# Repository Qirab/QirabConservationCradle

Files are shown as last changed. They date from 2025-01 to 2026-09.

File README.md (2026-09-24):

# Qirab™ Conservation Cradle - QCC50 & QCC70

حامل قِراب لترميم المخطوطات هو تصميم مفتوح المصدر لدعم وتثبيت المخطوطات اثناء عمليات الترميم والصيانة

An open-source manuscript repair support hardware design

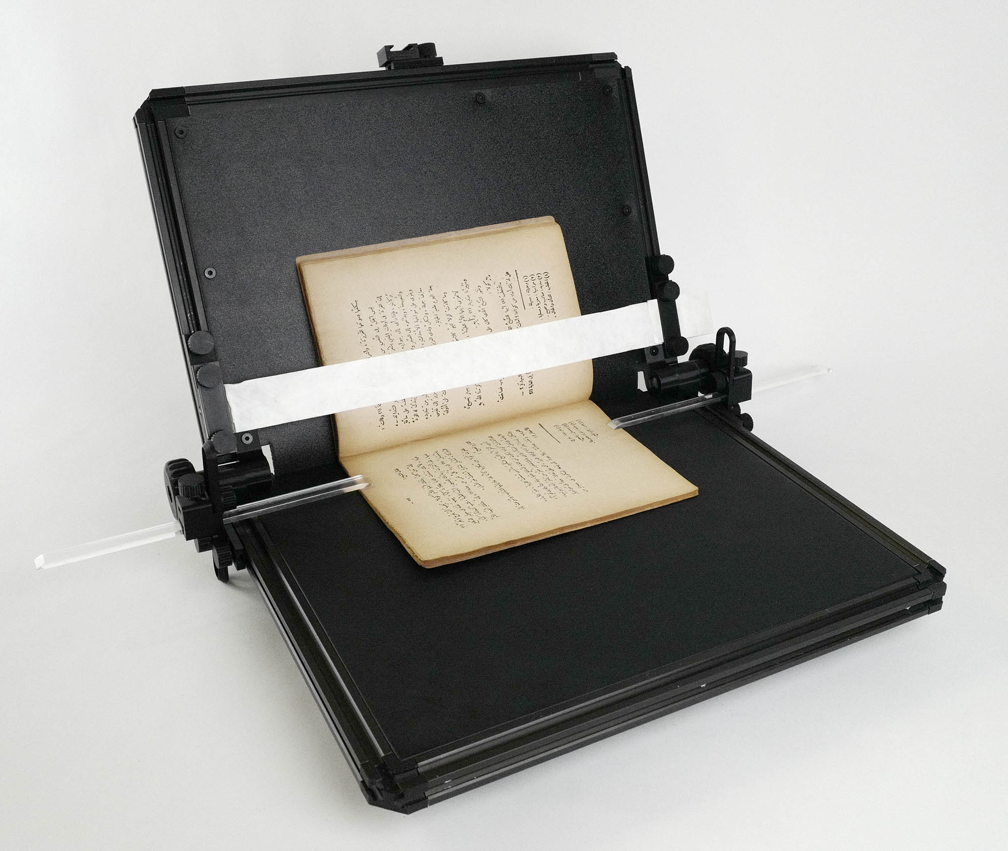
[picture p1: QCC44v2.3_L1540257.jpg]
QCC44v2.3

QC44 v2.3

تم تصميم حامل قِراب لترميم المخطوطات بهدف الحفاظ على المجلدات مفتوحة بشكل آمن أثناء عمليات الترميم والصيانة، والتحليل العلمي، والتوثيق، وأعمال الحفظ. يُسهل هذا الحامل تثبيت المجلدات دون الحاجة لاستخدام اليدين في وضعية ثابتة وقابلة للتعديل وبدون الحاجة للضغط الشديد.

إقرأ المزيد [حامل قِرَاب لترميم المخطوطات - QCC50](https://qirab.org/docs/hardware/conservationcradle/).

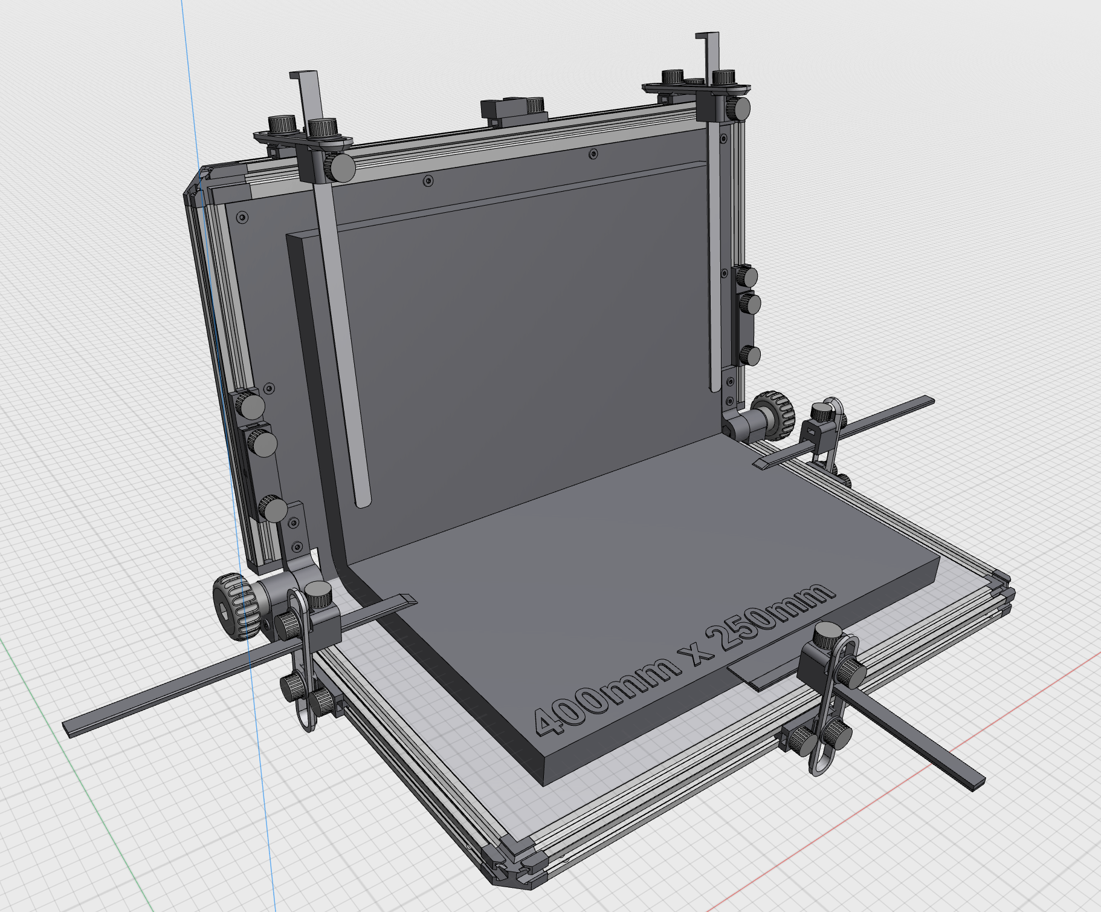
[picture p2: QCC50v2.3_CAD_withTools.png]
QCC55v2.3 CAD rendering with Tools

QCC50 v2.3 CAD rendering with Tools

The Qirab™ Conservation Cradle is an open-source book support design intended to securely hold books open during conservation treatment, scientific analysis, documentation, and preservation works. It facilitates a hands-free holding of the book in a stable and adjustable position without extreme pressure.

Read more on the [Qirab™ project page](https://qirab.org/en/docs/hardware/conservationcradle/).

<br />This work is licensed under a <a rel="license" href="http://creativecommons.org/licenses/by-sa/4.0/">Creative Commons Attribution-ShareAlike 4.0 International License</a>.

<br />هذا المُصنَّف مرخص بموجب <a rel="license" href="http://creativecommons.org/licenses/by-sa/4.0/">رخصة المشاع الإبداعي نَسب المُصنَّف - الترخيص بالمثل 4.0 دولي</a>.

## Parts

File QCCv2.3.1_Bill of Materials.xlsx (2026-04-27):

QCC Bill of Materials
Common Items for QCC50 and QCC75
Item Name | Item Count | Item Type | Item QID | Comment
Hinge Knob | 2 | 3D Print
Hinge Upper Right | 1 | 3D Print
Hinge Upper Left | 1 | 3D Print
Corner 40x20 Right | 1 | 3D Print
Corner 40x20 Left | 1 | 3D Print
~~Rubber Channel Guide~~ | DEPRECATED | 3D Print |  | Removed in v2.3.1
Hinge Left Bottom | 1 | 3D Print
Hinge Right Bottom | 1 | 3D Print
Corner 20x20 | 2 | 3D Print
Foot Lower | 4 | 3D Print
Foot Upper | 4 | 3D Print
Foot Drill Guide | 1 | 3D Print |  | For Assembly Only
OpenBuilds T-Nut | 14 | Hardware
6mm OpenBuilds M5 Low Profile | 6 | Hardware
10mm OpenBuilds M5 Low Profile | 4 | Hardware
15mm OpenBuilds M5 Low Profile | 12 | Hardware
20mm OpenBuilds M5 Low Profile | 0 | Hardware
25mm OpenBuilds M5 Low Profile | 4 | Hardware
M8 Zinc-Plated Steel Hex Nut 90591A161 | 2 | Hardware
M8 Medium-Strength Class 8.8 Steel Hex Head Screw 91280A548 | 2 | Hardware
Stainless Steel Oversized Washer 91116A330 | 6 | Hardware
Flat Head Screws for Particleboard and Fiberboard 90252A247 | 18 | Hardware
M6 Medium-Strength Class 8.8 Steel Hex Head Screw 91280A322 | 4 | Hardware
M6 Zinc-Plated Steel Hex Nut 90591A151 | 4 | Hardware
QCC50 Only Items
Item Name | Item Count | Item Type | Item QID | Comment
20x20x440 mm Frame Bar - OpenBuilds V-Slot Aluminum Profile | 2 | Aluminum
20x40x440 mm Frame Top - OpenBuilds V-Slot Aluminum Profile | 1 | Aluminum
20x40x267 Frame Side - OpenBuilds V-Slot Aluminum Profile | 2 | Aluminum
20x20x286 Base Side - OpenBuilds V-Slot Aluminum Profile | 2 | Aluminum
20x20x463 Front Base Bar - OpenBuilds V-Slot Aluminum Profile | 1 | Aluminum
IKEA Skrutt Desk Mat | 1 | Rubber |  | Cut to pattern; Clear or Black
Wood Counter Top 480x302x28mm IKEA | 1 | Wood |  | Cut from larger worktop
Box QCC50 | 4 | 3D Print
Box Lid QCC50 | 4 | 3D Print
QCC70 Only Items
Item Name | Item Count | Item Type | Item QID | Comment
20x20x610 mm Frame Bar - OpenBuilds V-Slot Aluminum Profile | 2 | Aluminum
20x40x610 mm Frame Top - OpenBuilds V-Slot Aluminum Profile | 1 | Aluminum
20x40x392 Frame Side - OpenBuilds V-Slot Aluminum Profile | 2 | Aluminum
20x20x411 Base Side - OpenBuilds V-Slot Aluminum Profile | 2 | Aluminum
20x20x633 Front Base Bar - OpenBuilds V-Slot Aluminum Profile | 1 | Aluminum
IKEA Skrutt Desk Mat | 1 | Rubber |  | Mostly uncut; Clear or Black
Wood Counter Top 640x427x28mm IKEA | 1 | Wood |  | Cut from larger worktop
Box QCC70 | 4 | 3D Print
Box Lid QCC70 | 4 | 3D Print
QCC44 Only Items - Development Cradle
Item Name | Item Count | Item Type | Item QID | Comment
20x20x362mm Frame Bar - OpenBuilds V-Slot Aluminum Profile | 2 | Aluminum
20x40x362 Frame Top - OpenBuilds V-Slot Aluminum Profile | 1 | Aluminum
20x40x257 Frame Side - OpenBuilds V-Slot Aluminum Profile | 2 | Aluminum
20x20x303 Base Side - OpenBuilds V-Slot Aluminum Profile | 2 | Aluminum
20x20x385 Front Base Bar - OpenBuilds V-Slot Aluminum Profile | 1 | Aluminum
IKEA Skrutt Desk Mat | 1 | Rubber |  | Cut to pattern; Clear or Black
Wood Counter Top 402x312x28mm IKEA | 1 | Wood |  | Cut from larger worktop
Box QCC44 | 4 | 3D Print
Box Lid QCC44 | 4 | 3D Print

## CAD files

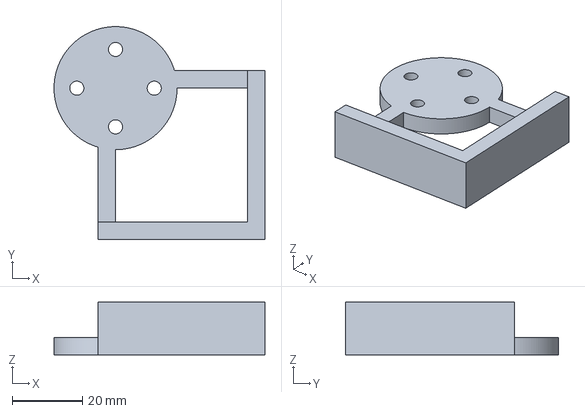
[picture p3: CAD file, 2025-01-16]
3DPRINT/3MF/QCC Foot Drill Guide (for assembly only).3mf
60.0 x 60.5 x 15.0 mm

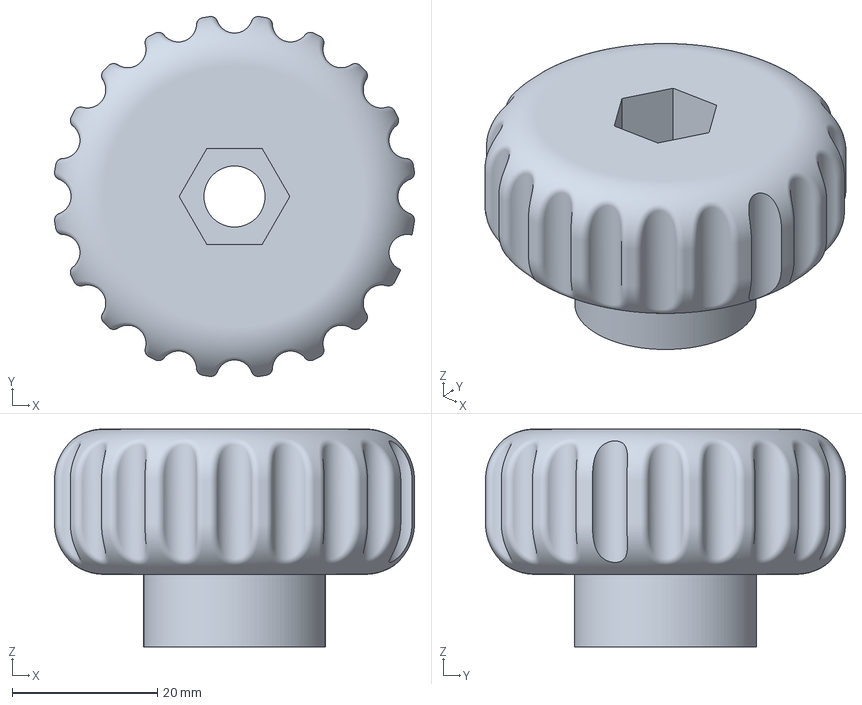
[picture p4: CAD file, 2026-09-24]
3DPRINT/3MF/QCC Hinge Knob.3mf
49.6 x 49.6 x 30.0 mm

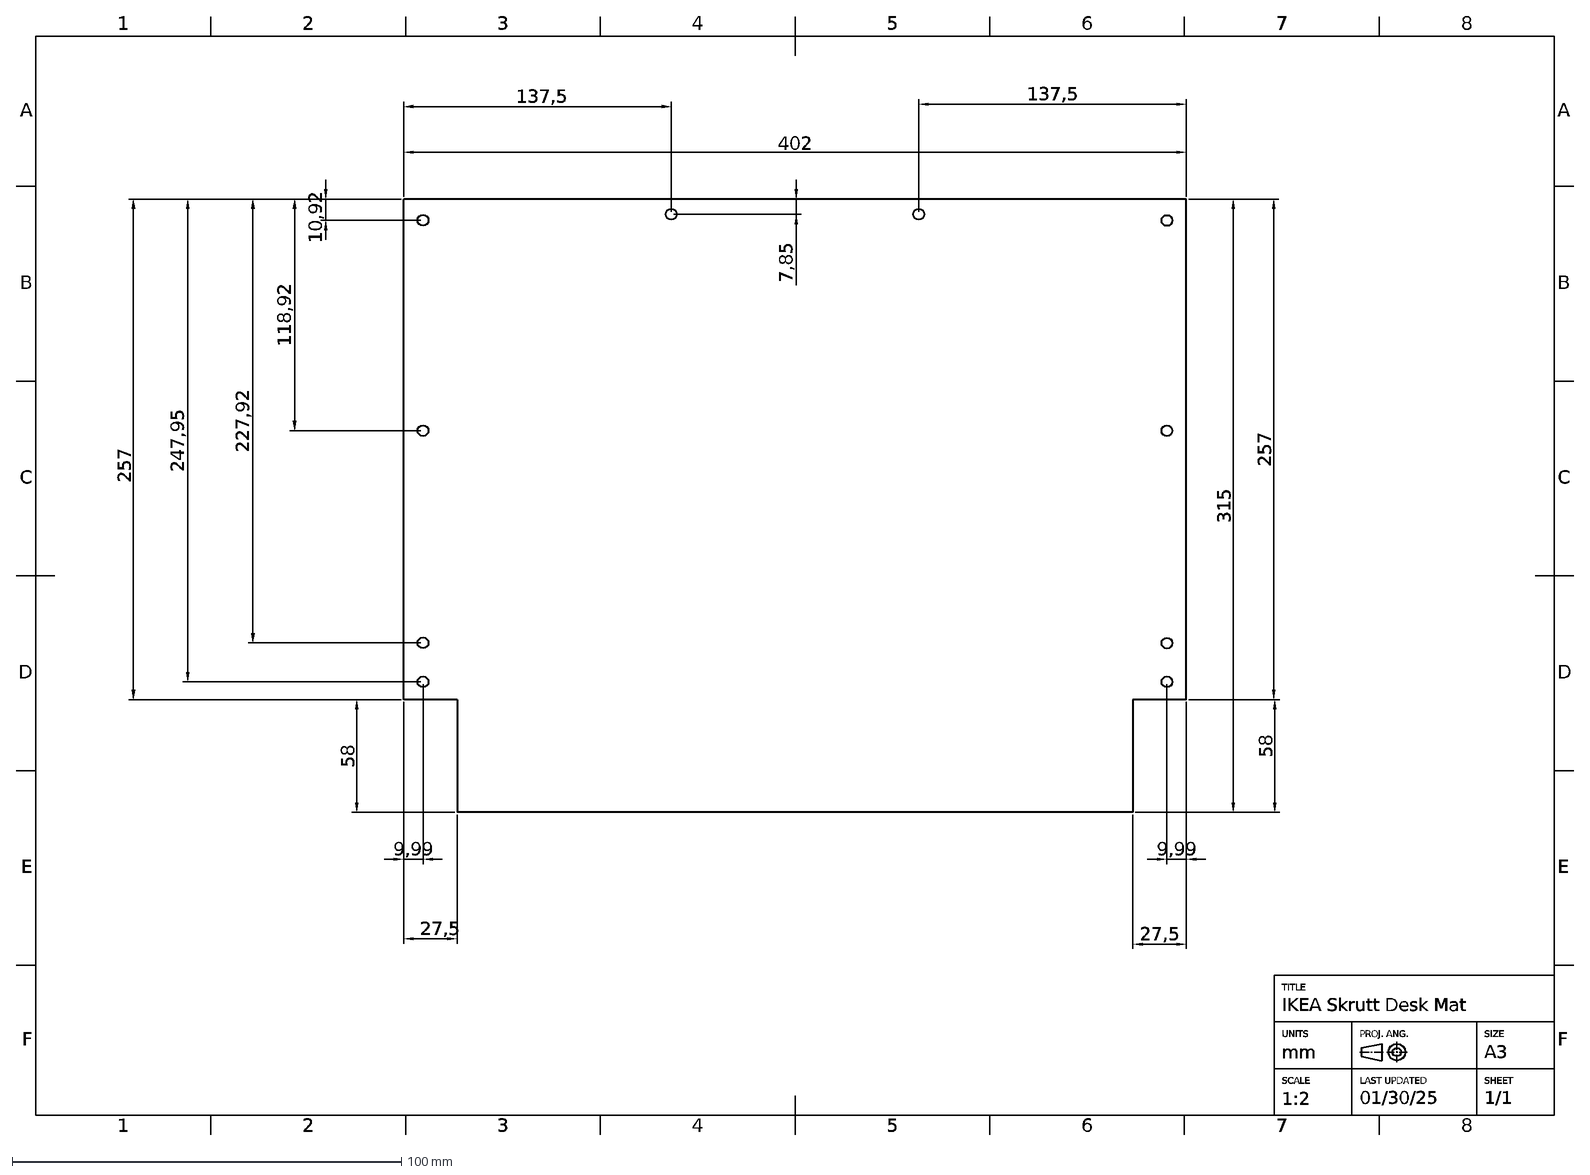
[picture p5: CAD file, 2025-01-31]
PDF/QCC44/QCC44 V2.3 IKEA SKRUT MAT.dxf
7,85
257
58
27,5
137,5
247,95
227,92
118,92
10,92
9,99
315
402
1
2
3
4
5
6
7
8
F
E
D
C
B
A
TITLE
IKEA Skrutt Desk Mat
UNITS
mm
PROJ. ANG.
SIZE
A3
SCALE
1:2
LAST UPDATED
01/30/25
SHEET
1/1

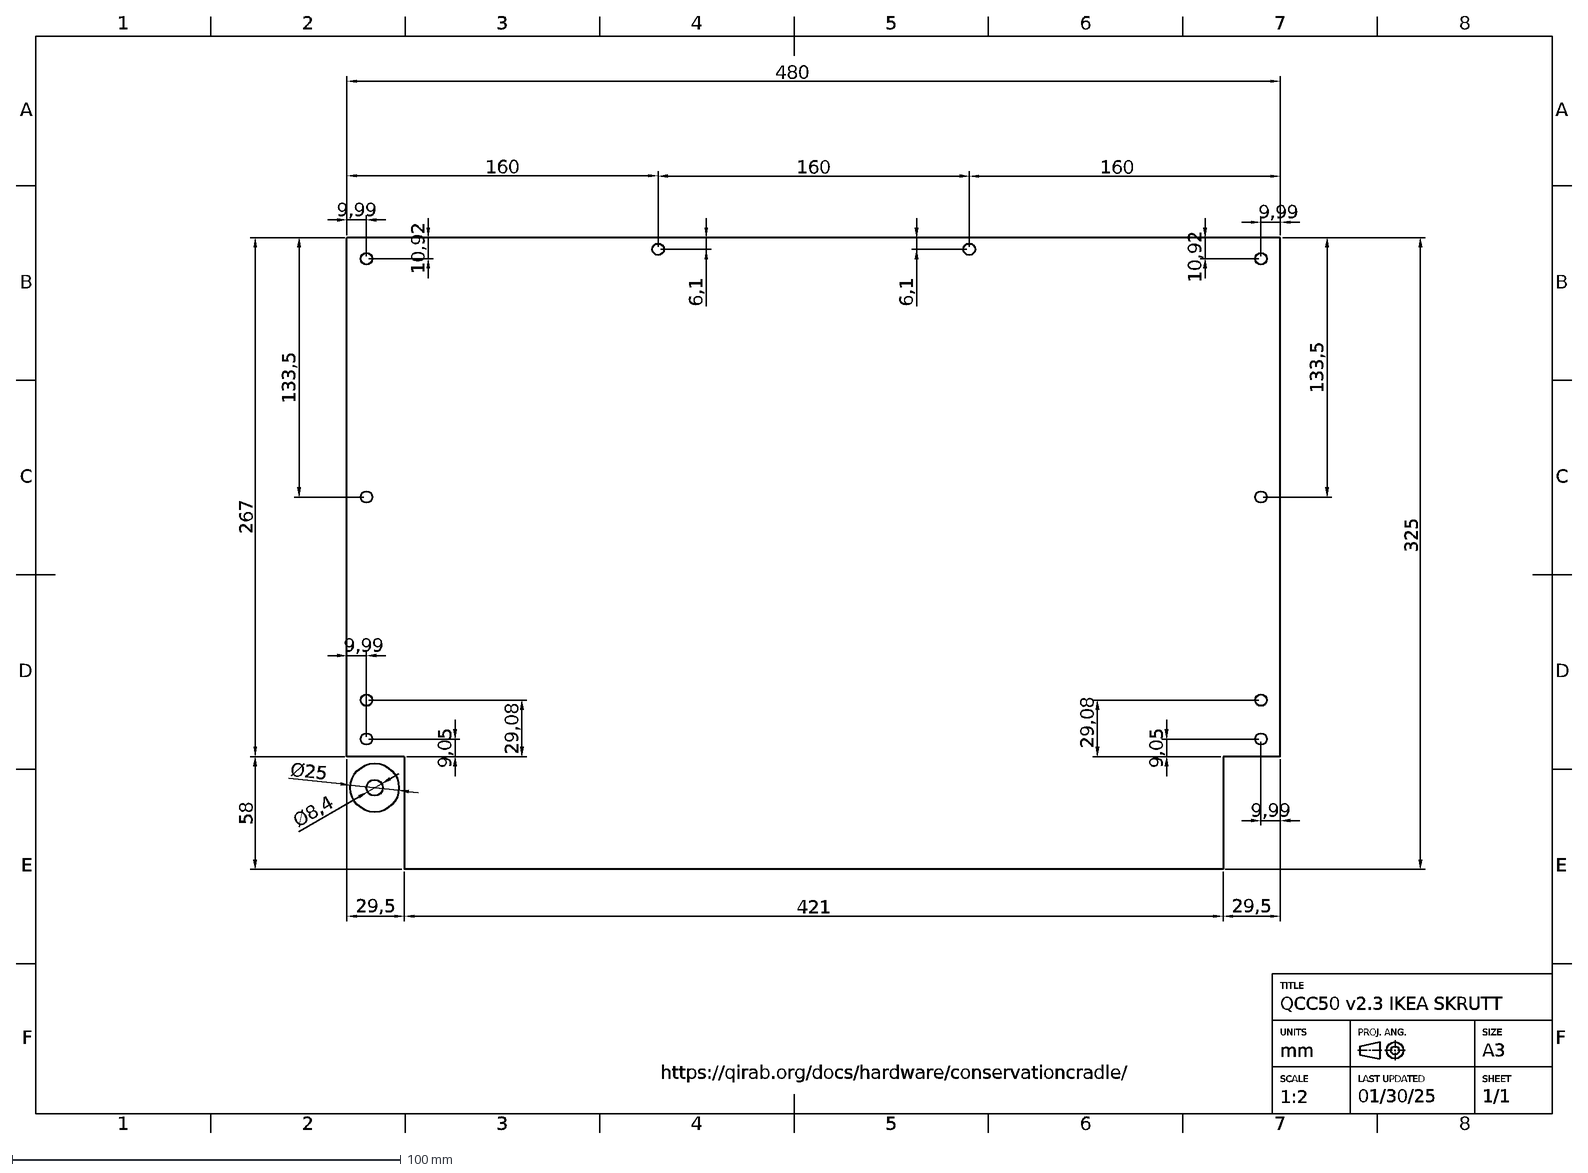
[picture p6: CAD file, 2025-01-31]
PDF/QCC50 v2.3 IKEA SKRUTT.dxf
58
133,5
160
Ø25
10,92
29,08
Ø8,4
9,99
421
29,5
325
6,1
480
9,05
267
1
2
3
4
5
6
7
8
F
E
D
C
B
A
TITLE
QCC50 v2.3 IKEA SKRUTT
UNITS
mm
PROJ. ANG.
SIZE
A3
https://qirab.org/docs/hardware/conservationcradle/
01/30/25
1:2
LAST UPDATED
SHEET
SCALE
1/1

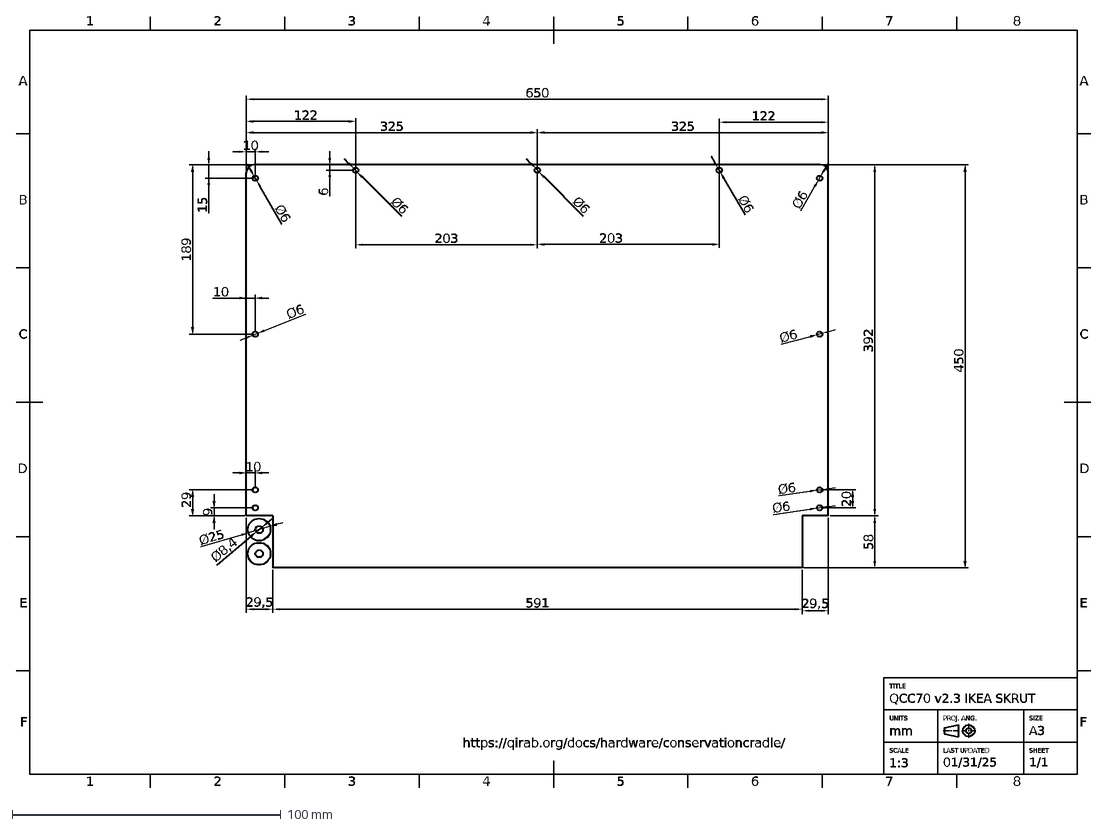
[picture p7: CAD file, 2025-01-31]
PDF/QCC70/QCC70 v2.3 IKEA SKRUT.dxf
650
450
58
392
29,5
591
10
9
29
189
15
6
122
325
Ø6
20
203
Ø25
Ø8,4
1
2
3
4
5
7
8
F
E
D
C
B
A
https://qirab.org/docs/hardware/conservationcradle/
SIZE
QCC70 v2.3 IKEA SKRUT
UNITS
mm
PROJ. ANG.
A3
SCALE
1:3
LAST UPDATED
01/31/25
TITLE
SHEET
1/1

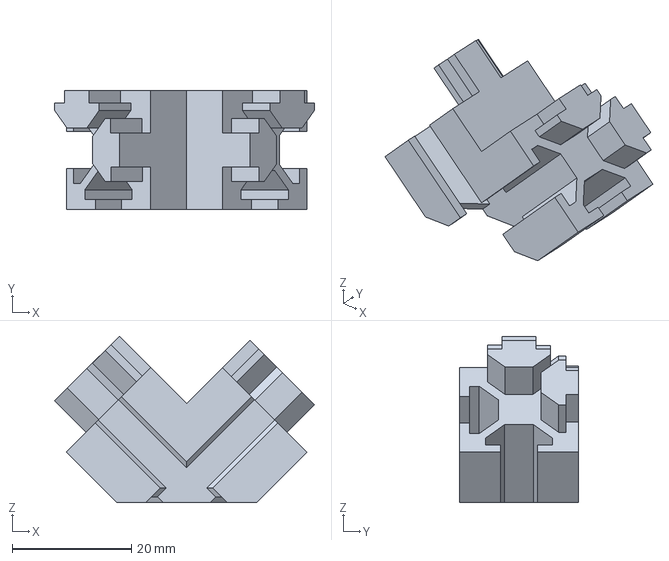
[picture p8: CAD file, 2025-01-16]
3DPRINT/3MF/QCC Corner 20.3mf
43.6 x 20.0 x 27.8 mm

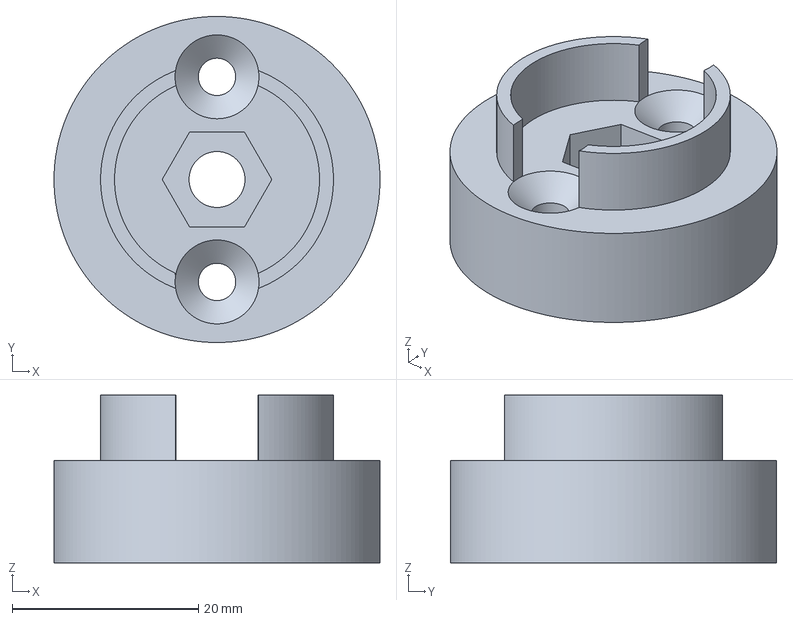
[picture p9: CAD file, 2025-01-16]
3DPRINT/3MF/QCC Foot Upper.3mf
35.0 x 35.0 x 18.0 mm

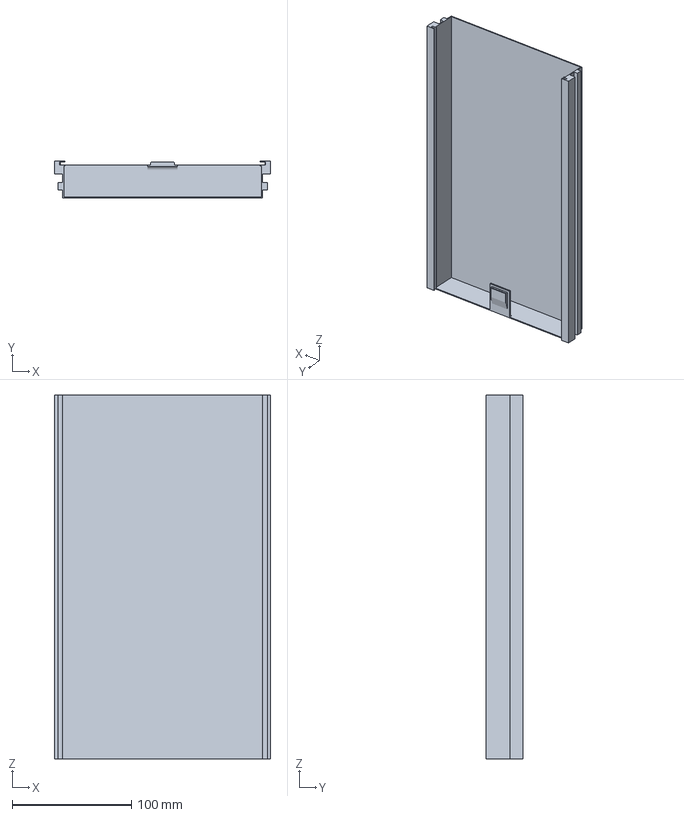
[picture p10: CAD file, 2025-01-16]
3DPRINT/3MF/QCC Box QCC70.3mf
181.2 x 31.0 x 305.0 mm

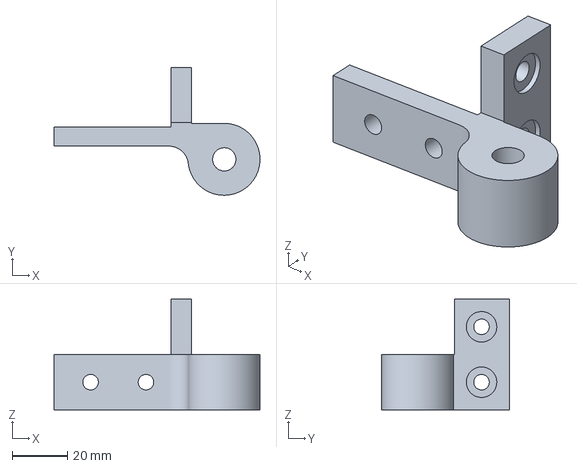
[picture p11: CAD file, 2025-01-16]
3DPRINT/3MF/QCC Hinge Upper Right.3mf
74.4 x 46.1 x 40.0 mm

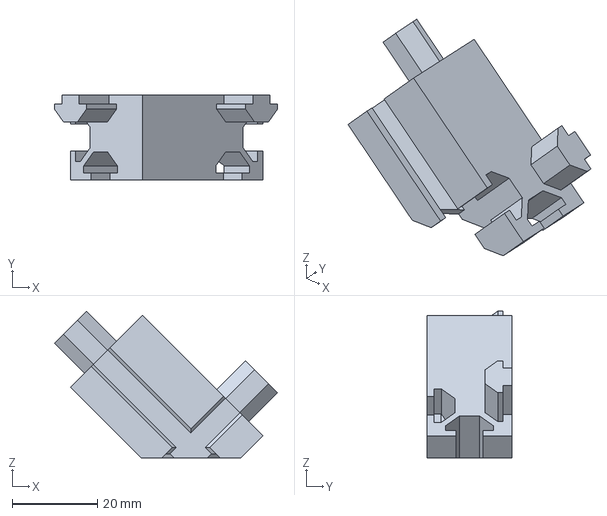
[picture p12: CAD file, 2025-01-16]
3DPRINT/3MF/QCC Corner 40 Left.3mf
52.4 x 20.0 x 34.5 mm

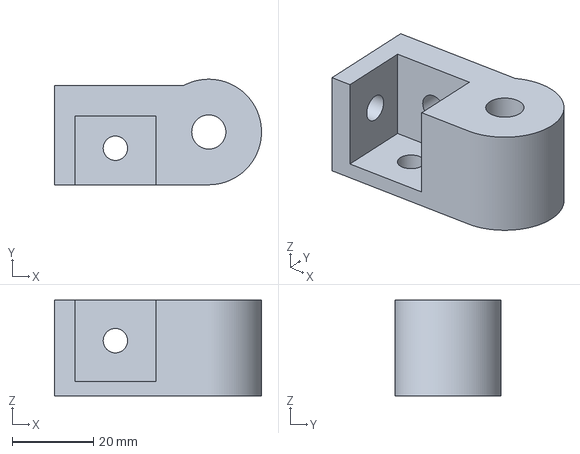
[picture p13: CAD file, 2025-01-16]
3DPRINT/3MF/QCC Hinge Right Bottom.3mf
51.0 x 26.0 x 23.6 mm

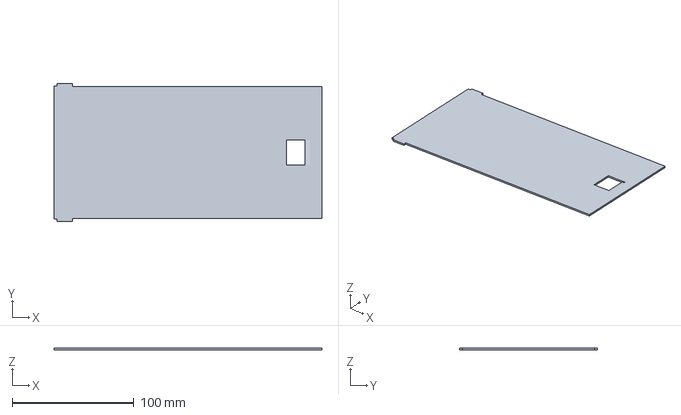
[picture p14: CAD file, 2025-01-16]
3DPRINT/3MF/QCC Box Lid QCC50.3mf
220.0 x 113.0 x 1.50 mm

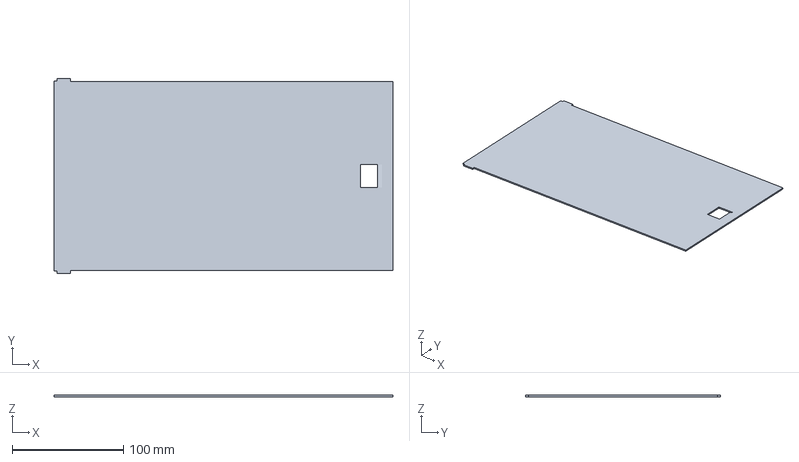
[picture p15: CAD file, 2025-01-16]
3DPRINT/3MF/QCC Box Lid QCC70.3mf
305.0 x 175.5 x 1.50 mm

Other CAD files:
3DPRINT/3MF/QCC Hinge Left Bottom.3mf
3DPRINT/3MF/QCC Corner 40 Right.3mf
3DPRINT/3MF/QCC Box Lid QCC44.3mf
3DPRINT/3MF/QCC Box QCC44.3mf
3DPRINT/3MF/QCC Box QCC50.3mf
3DPRINT/3MF/QCC Foot Lower.3mf
3DPRINT/3MF/QCC Hinge Upper Left.3mf

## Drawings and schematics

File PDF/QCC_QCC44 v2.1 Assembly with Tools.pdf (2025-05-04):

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

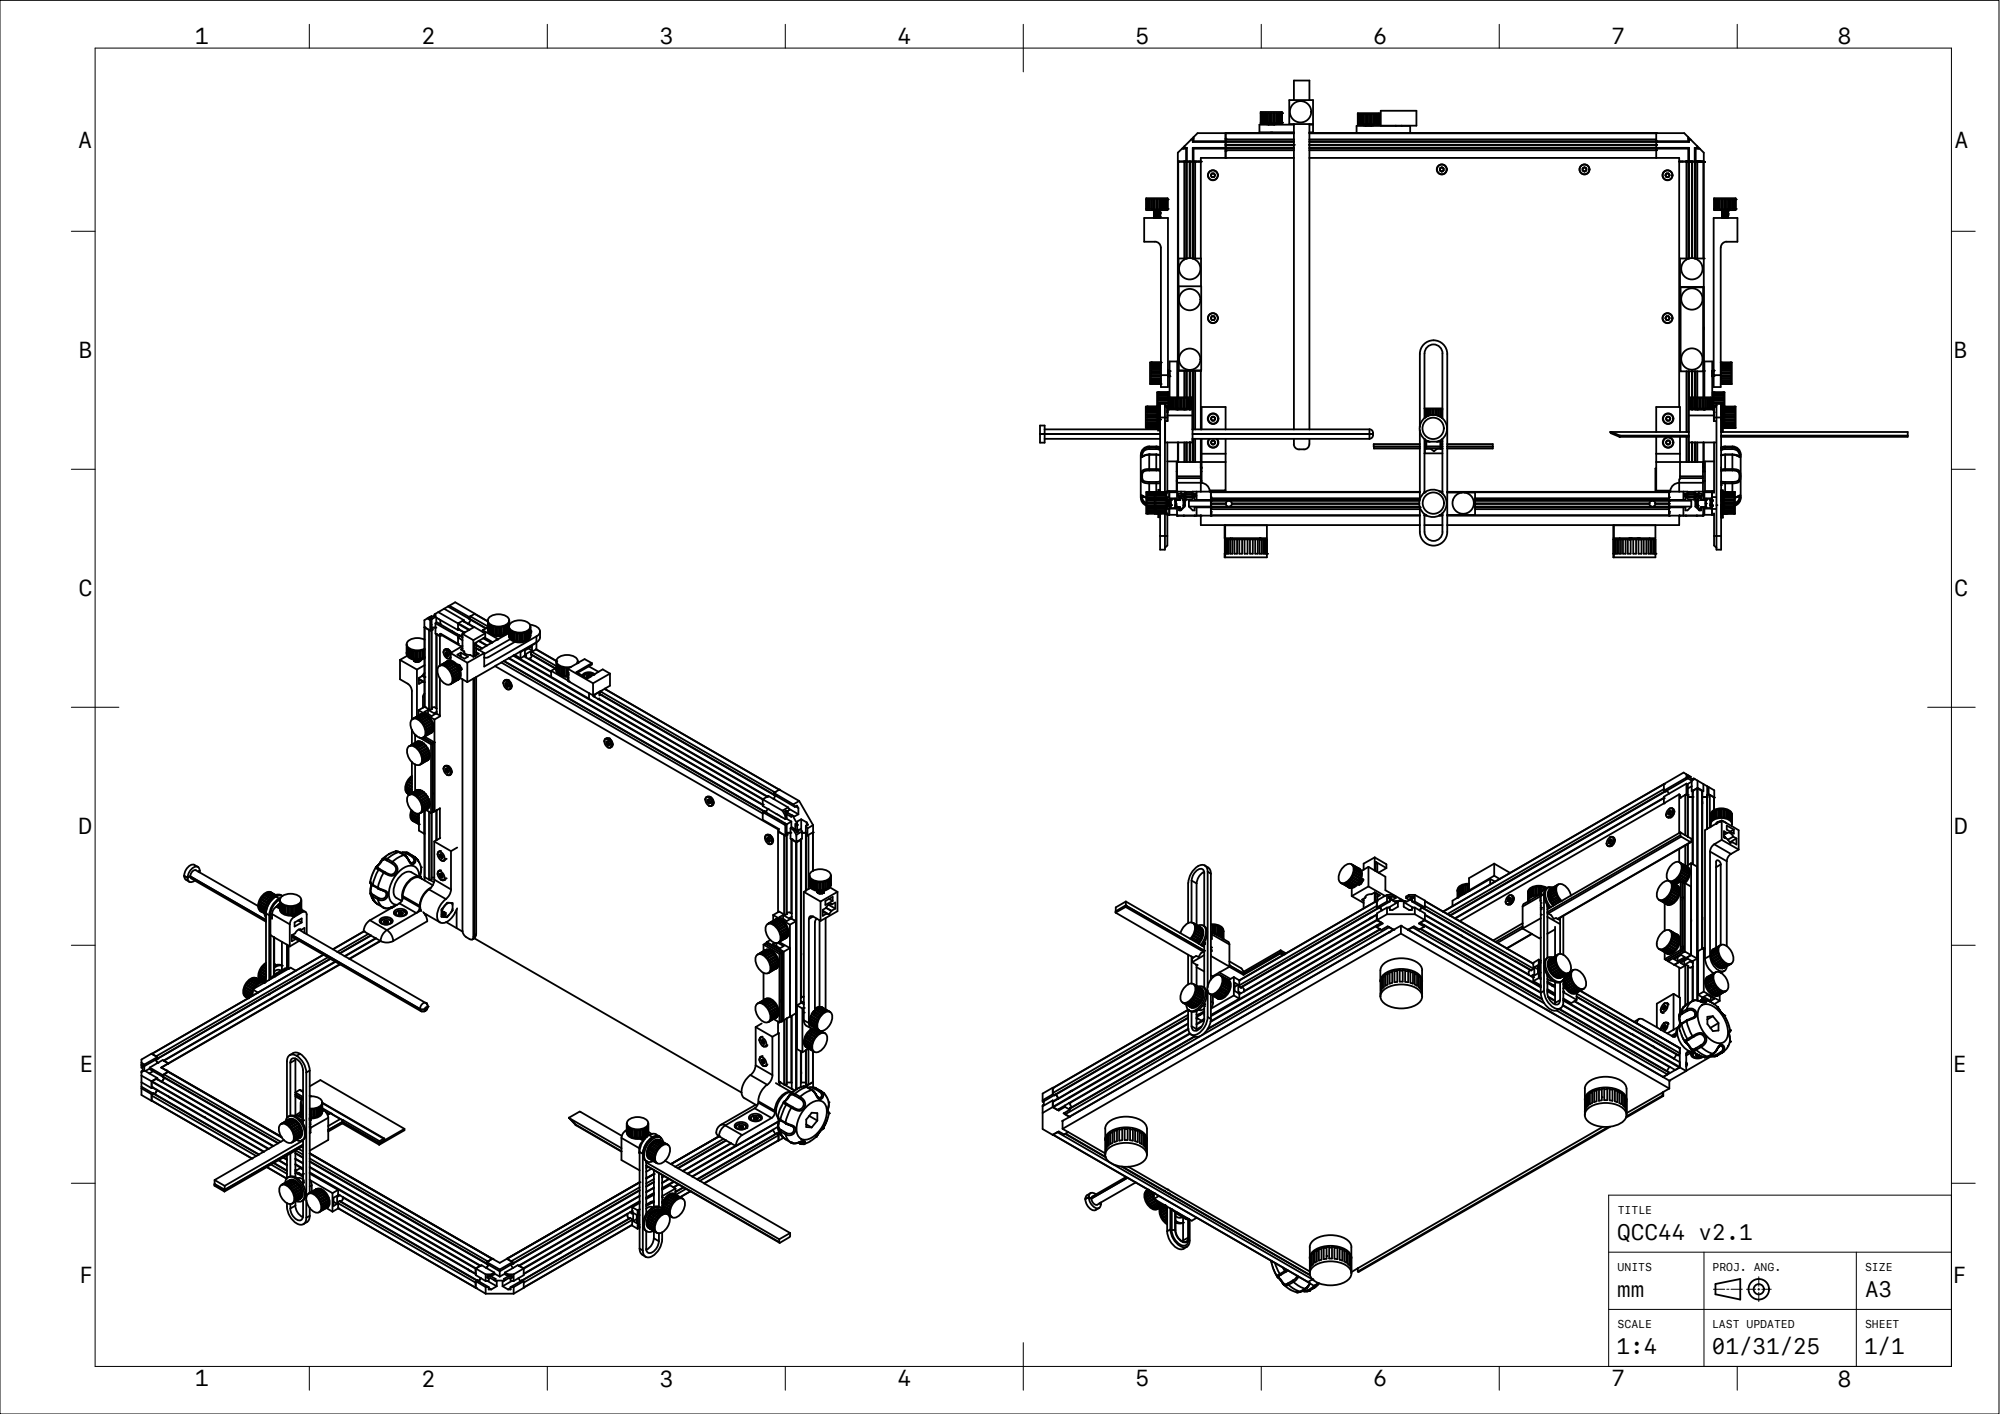
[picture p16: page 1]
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

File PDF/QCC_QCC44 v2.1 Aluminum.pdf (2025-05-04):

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

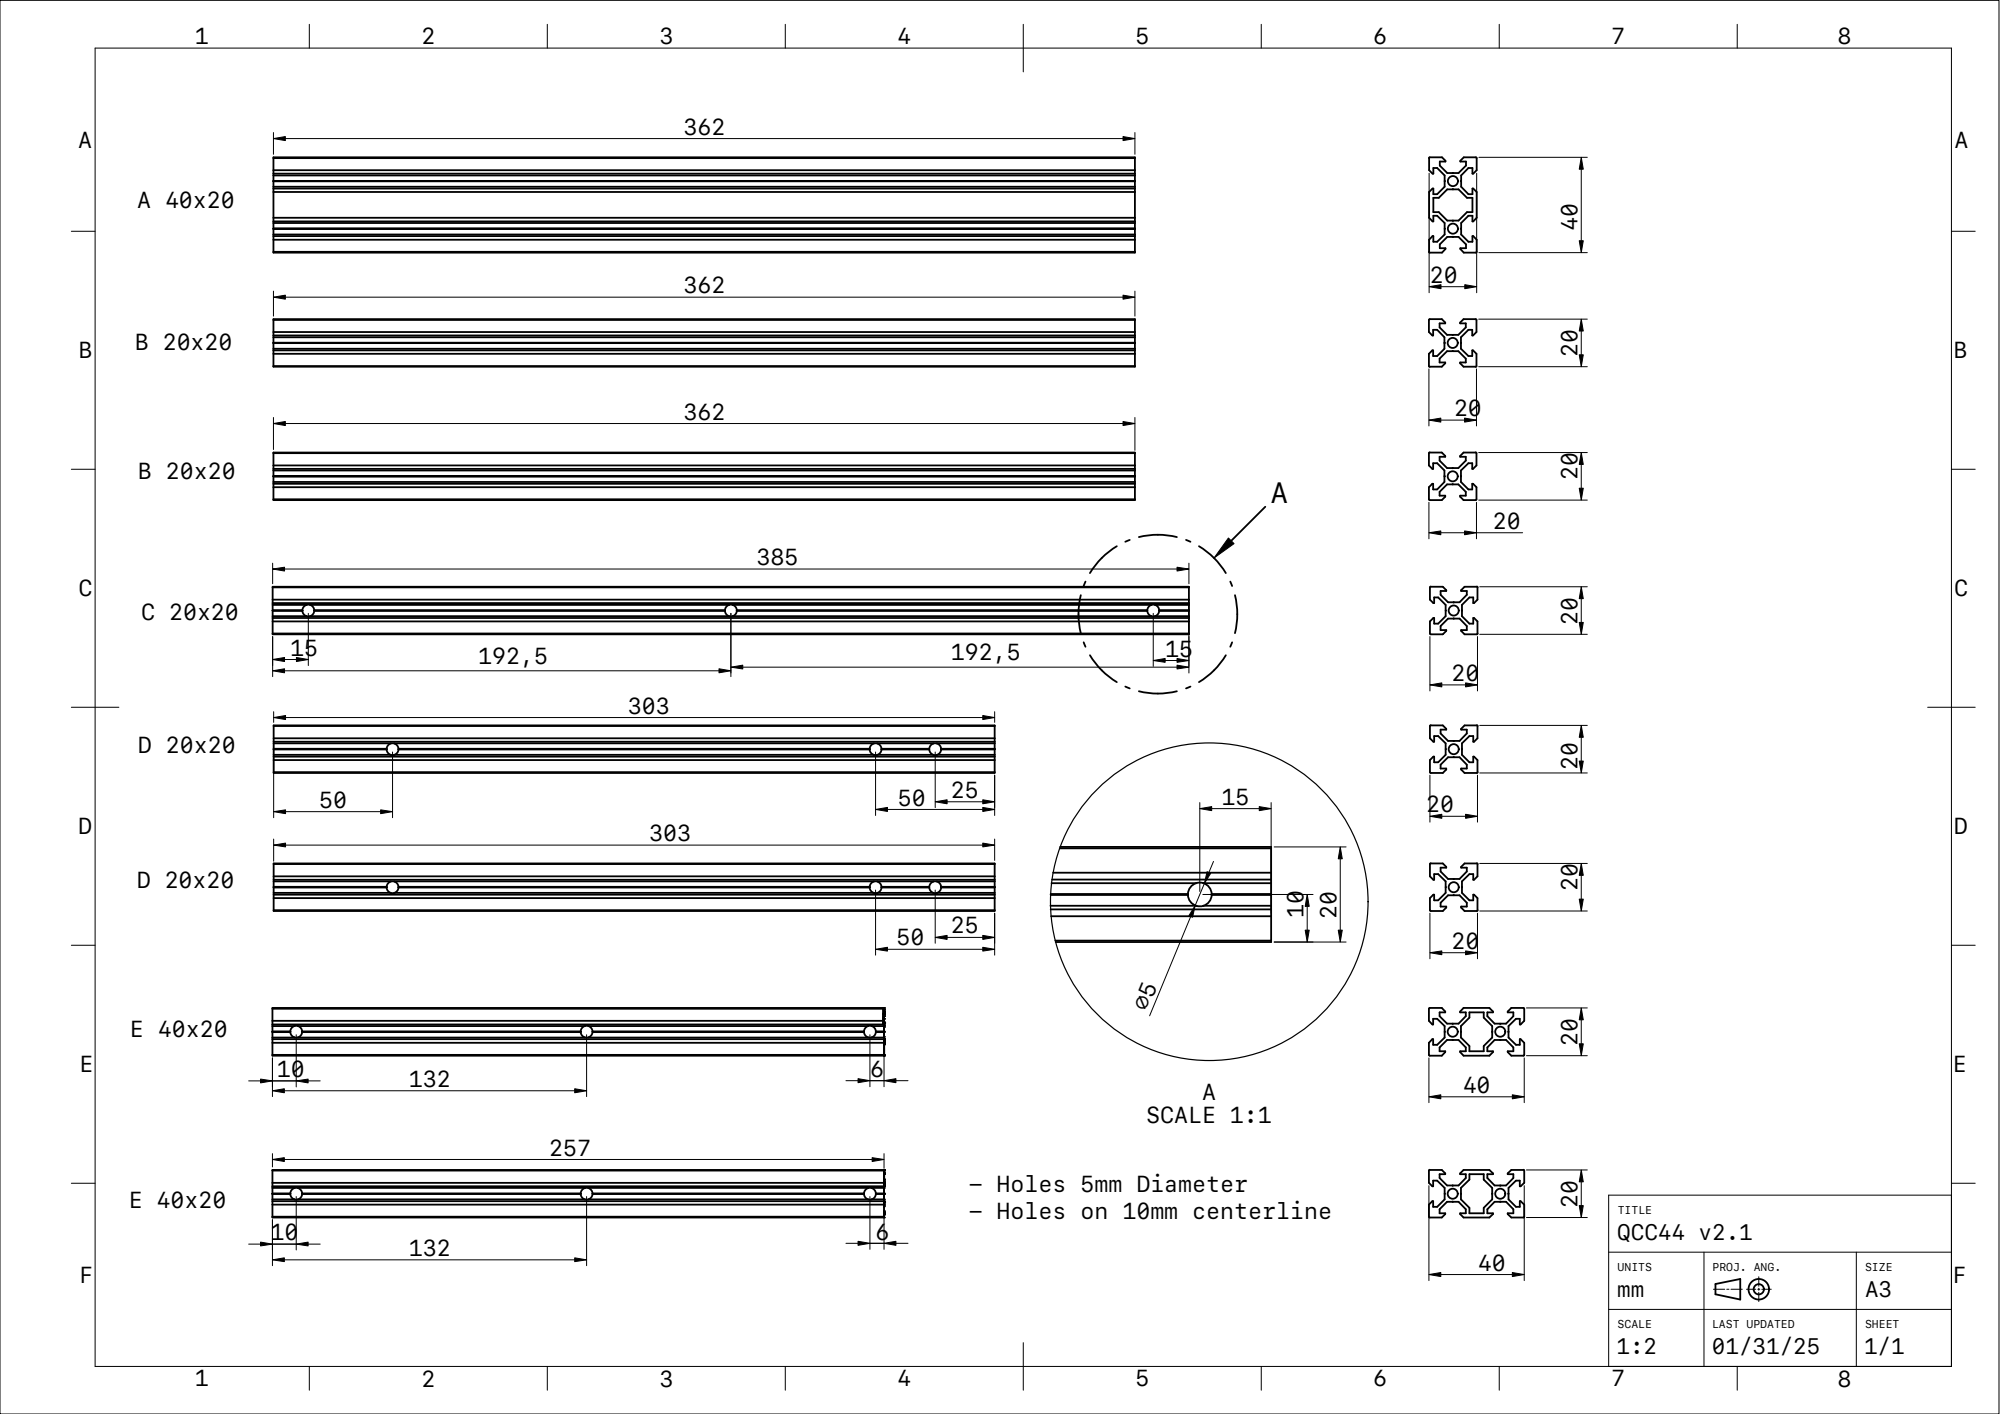
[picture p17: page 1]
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

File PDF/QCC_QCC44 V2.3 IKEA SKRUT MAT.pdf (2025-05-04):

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

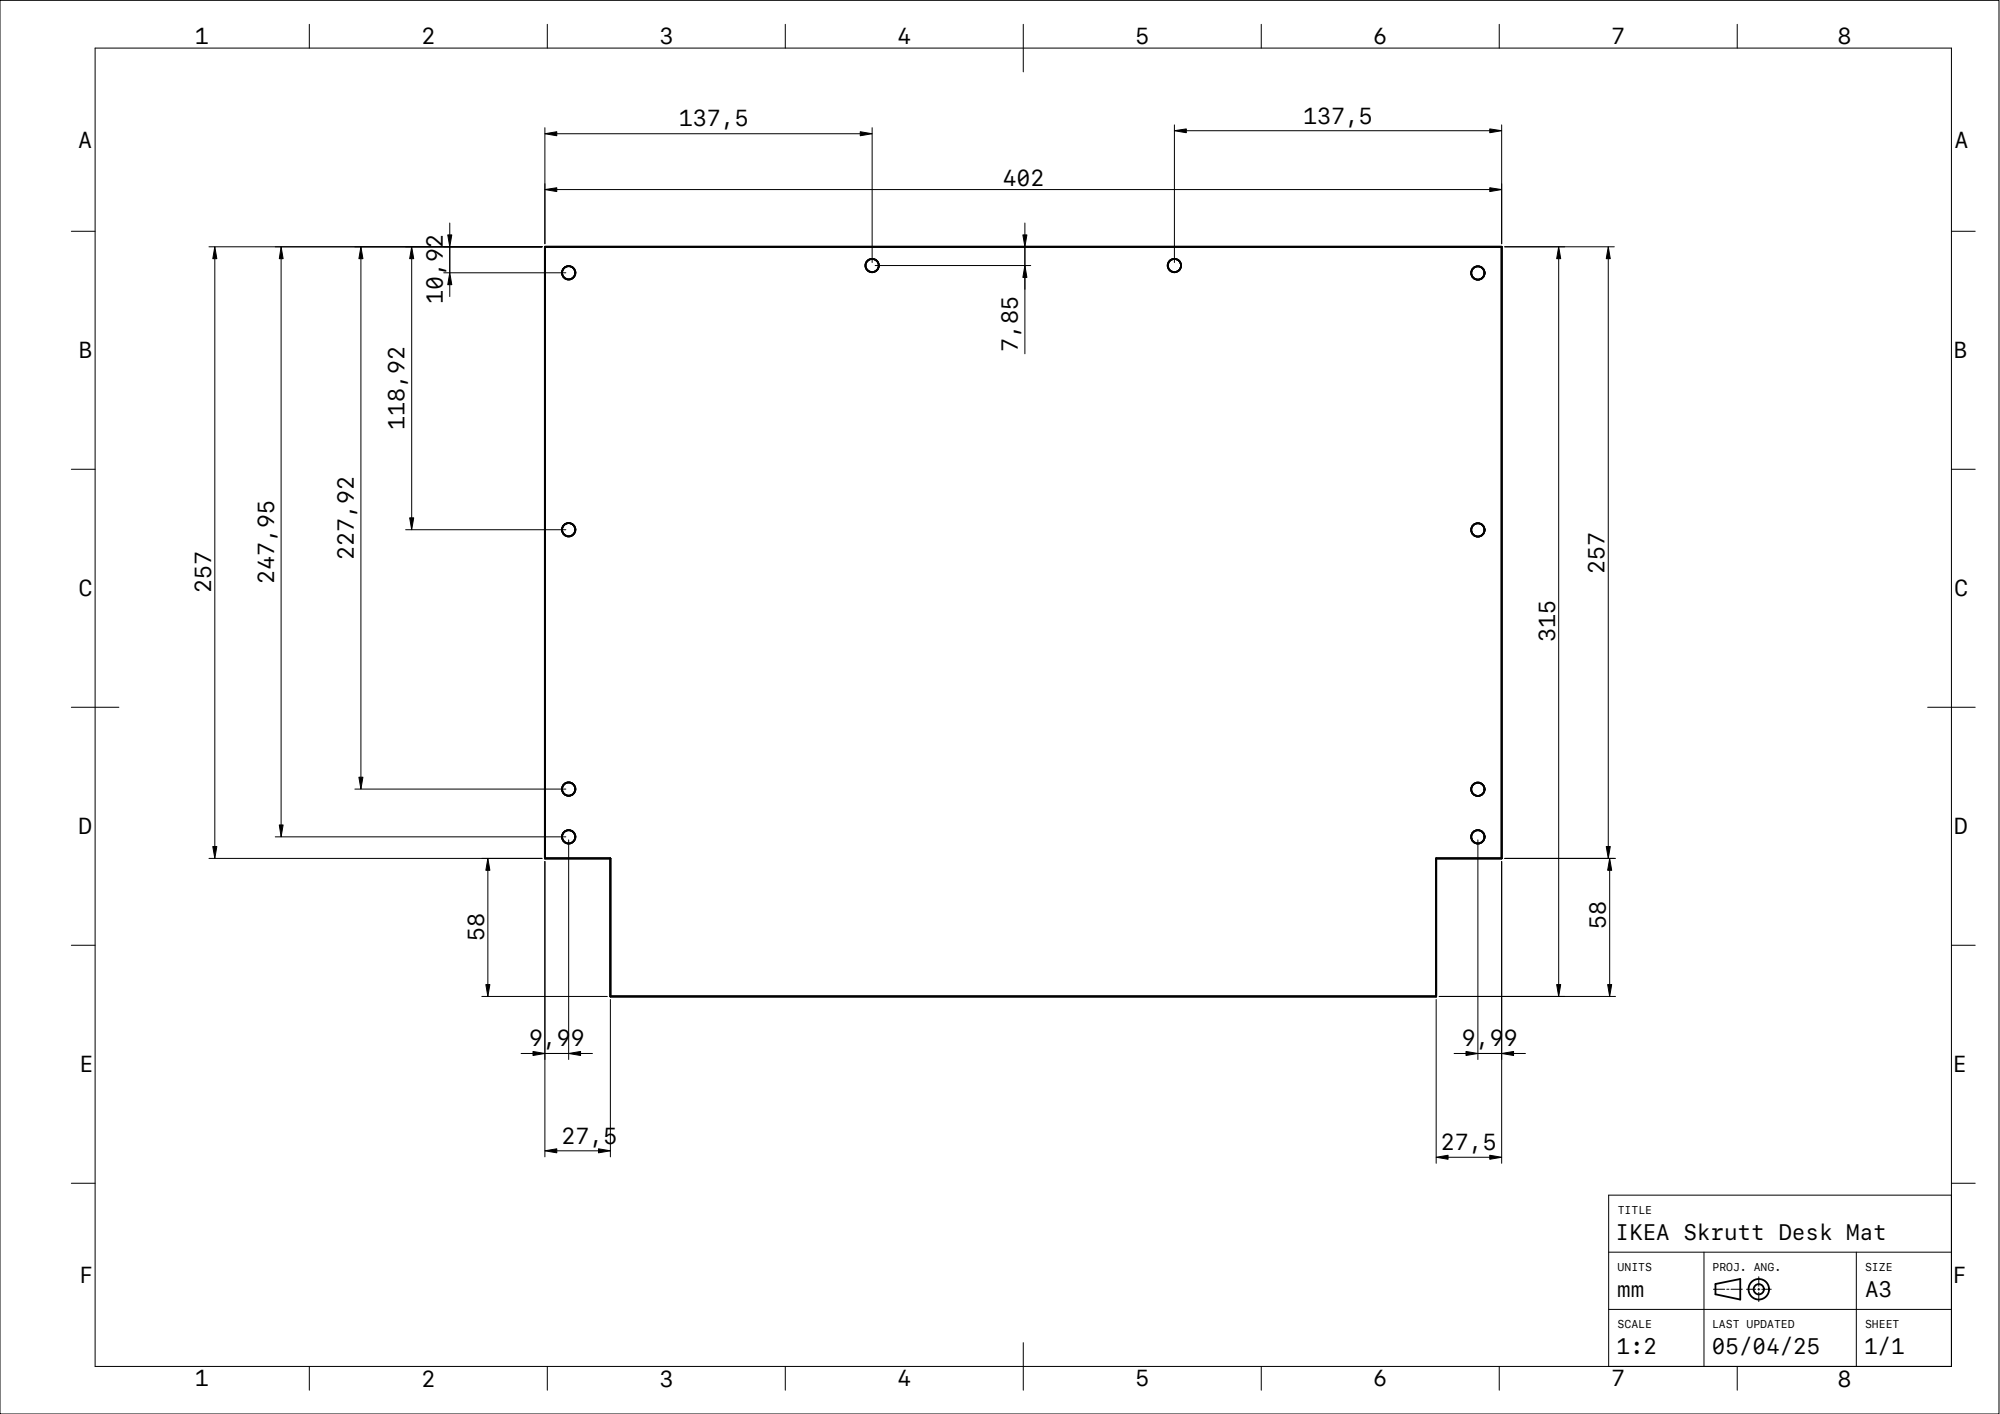
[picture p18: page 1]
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

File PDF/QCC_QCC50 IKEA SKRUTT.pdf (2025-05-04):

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

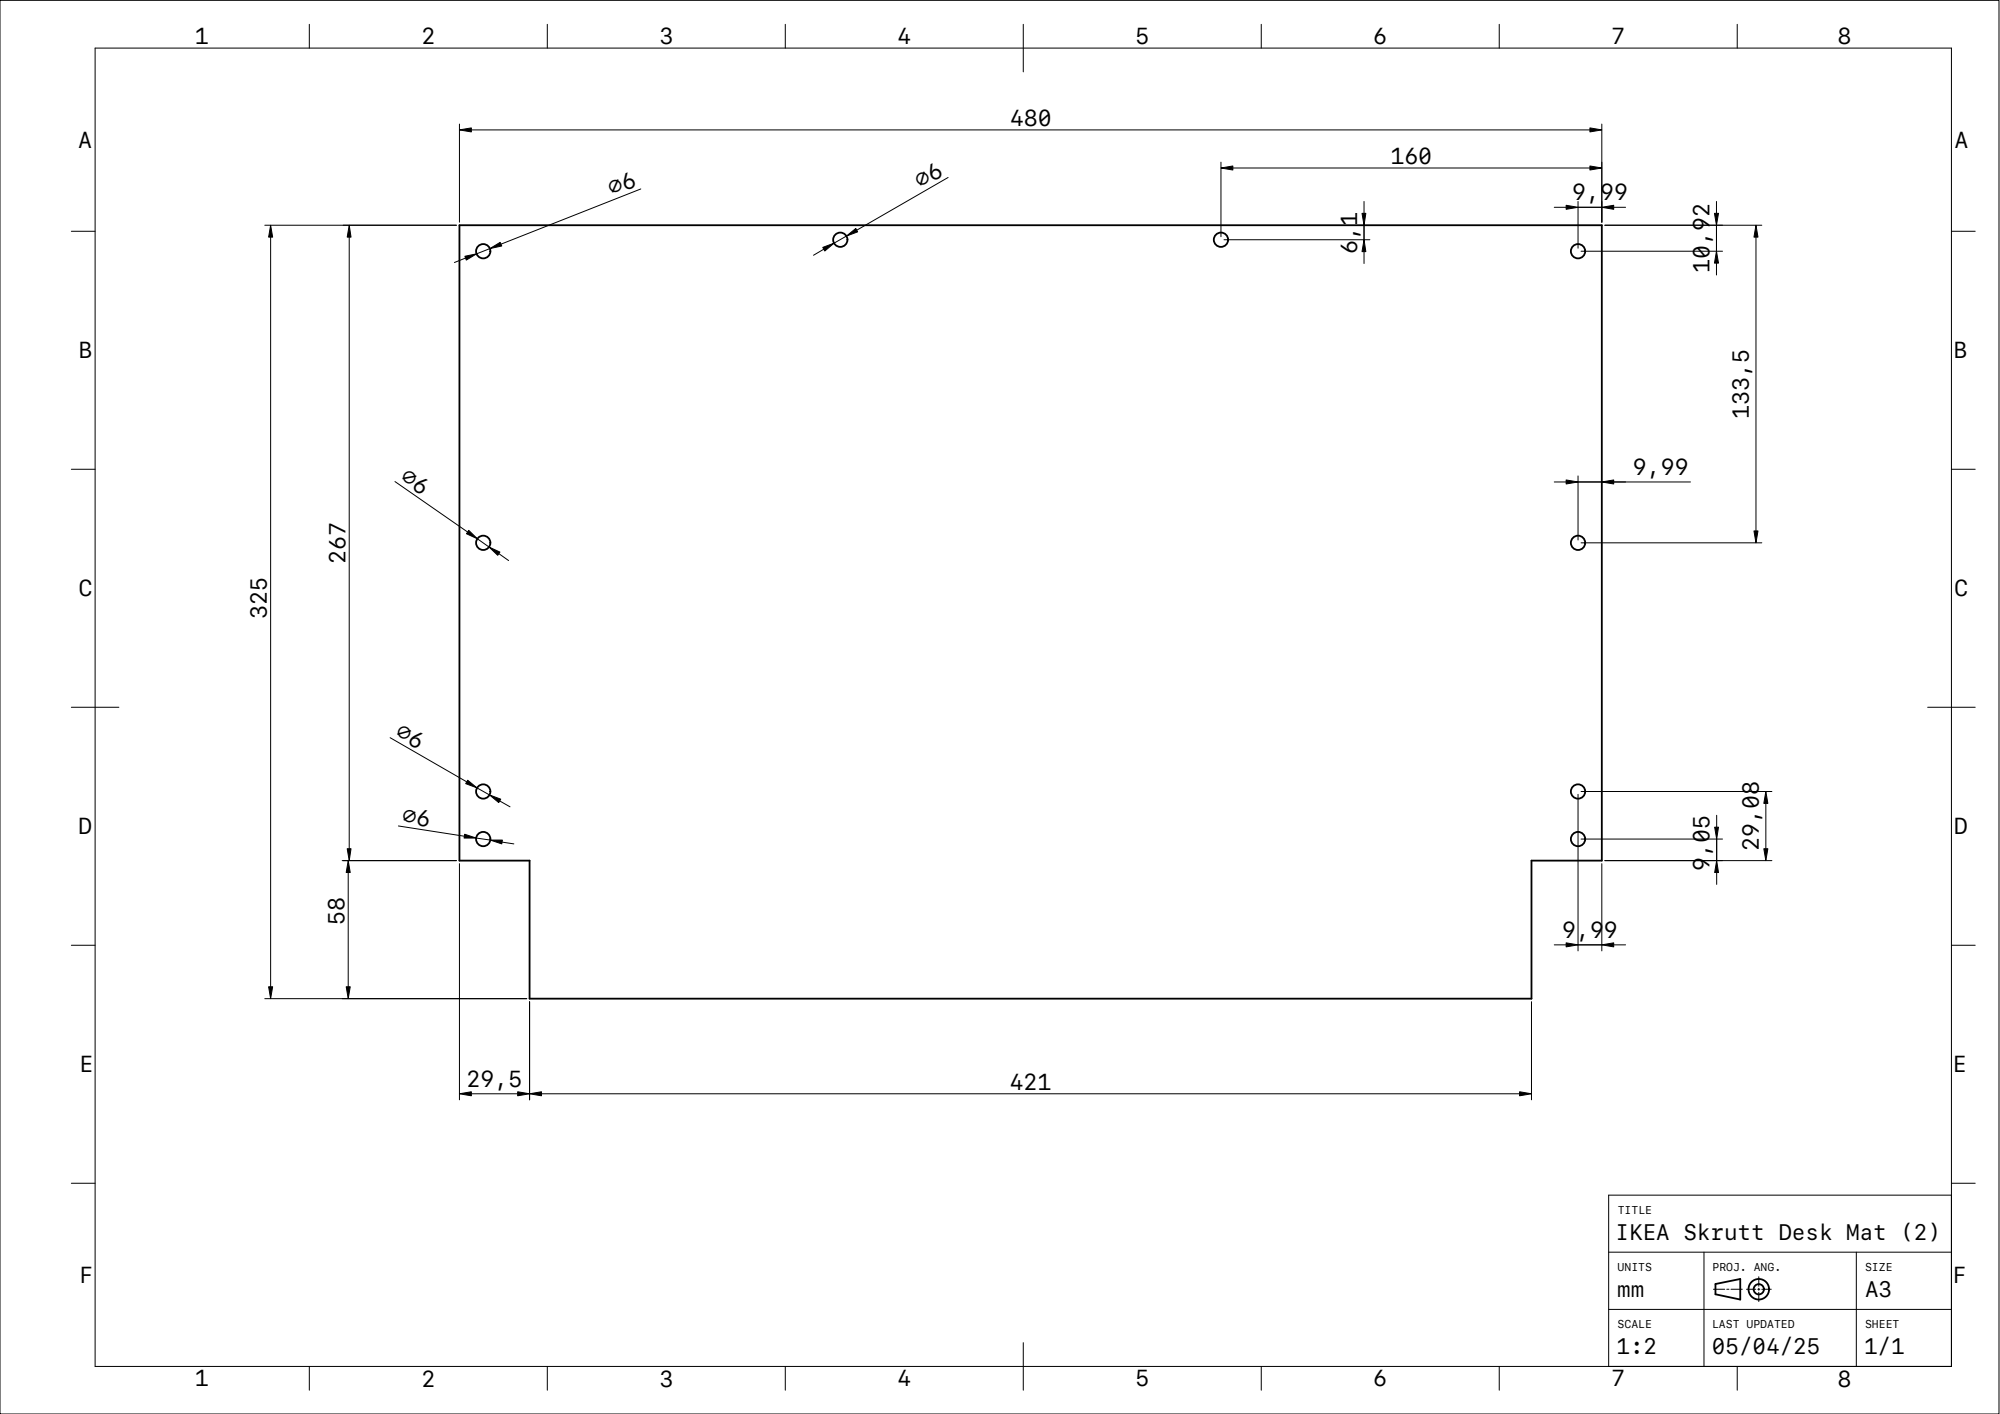
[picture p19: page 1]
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

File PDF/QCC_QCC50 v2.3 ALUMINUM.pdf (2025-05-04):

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

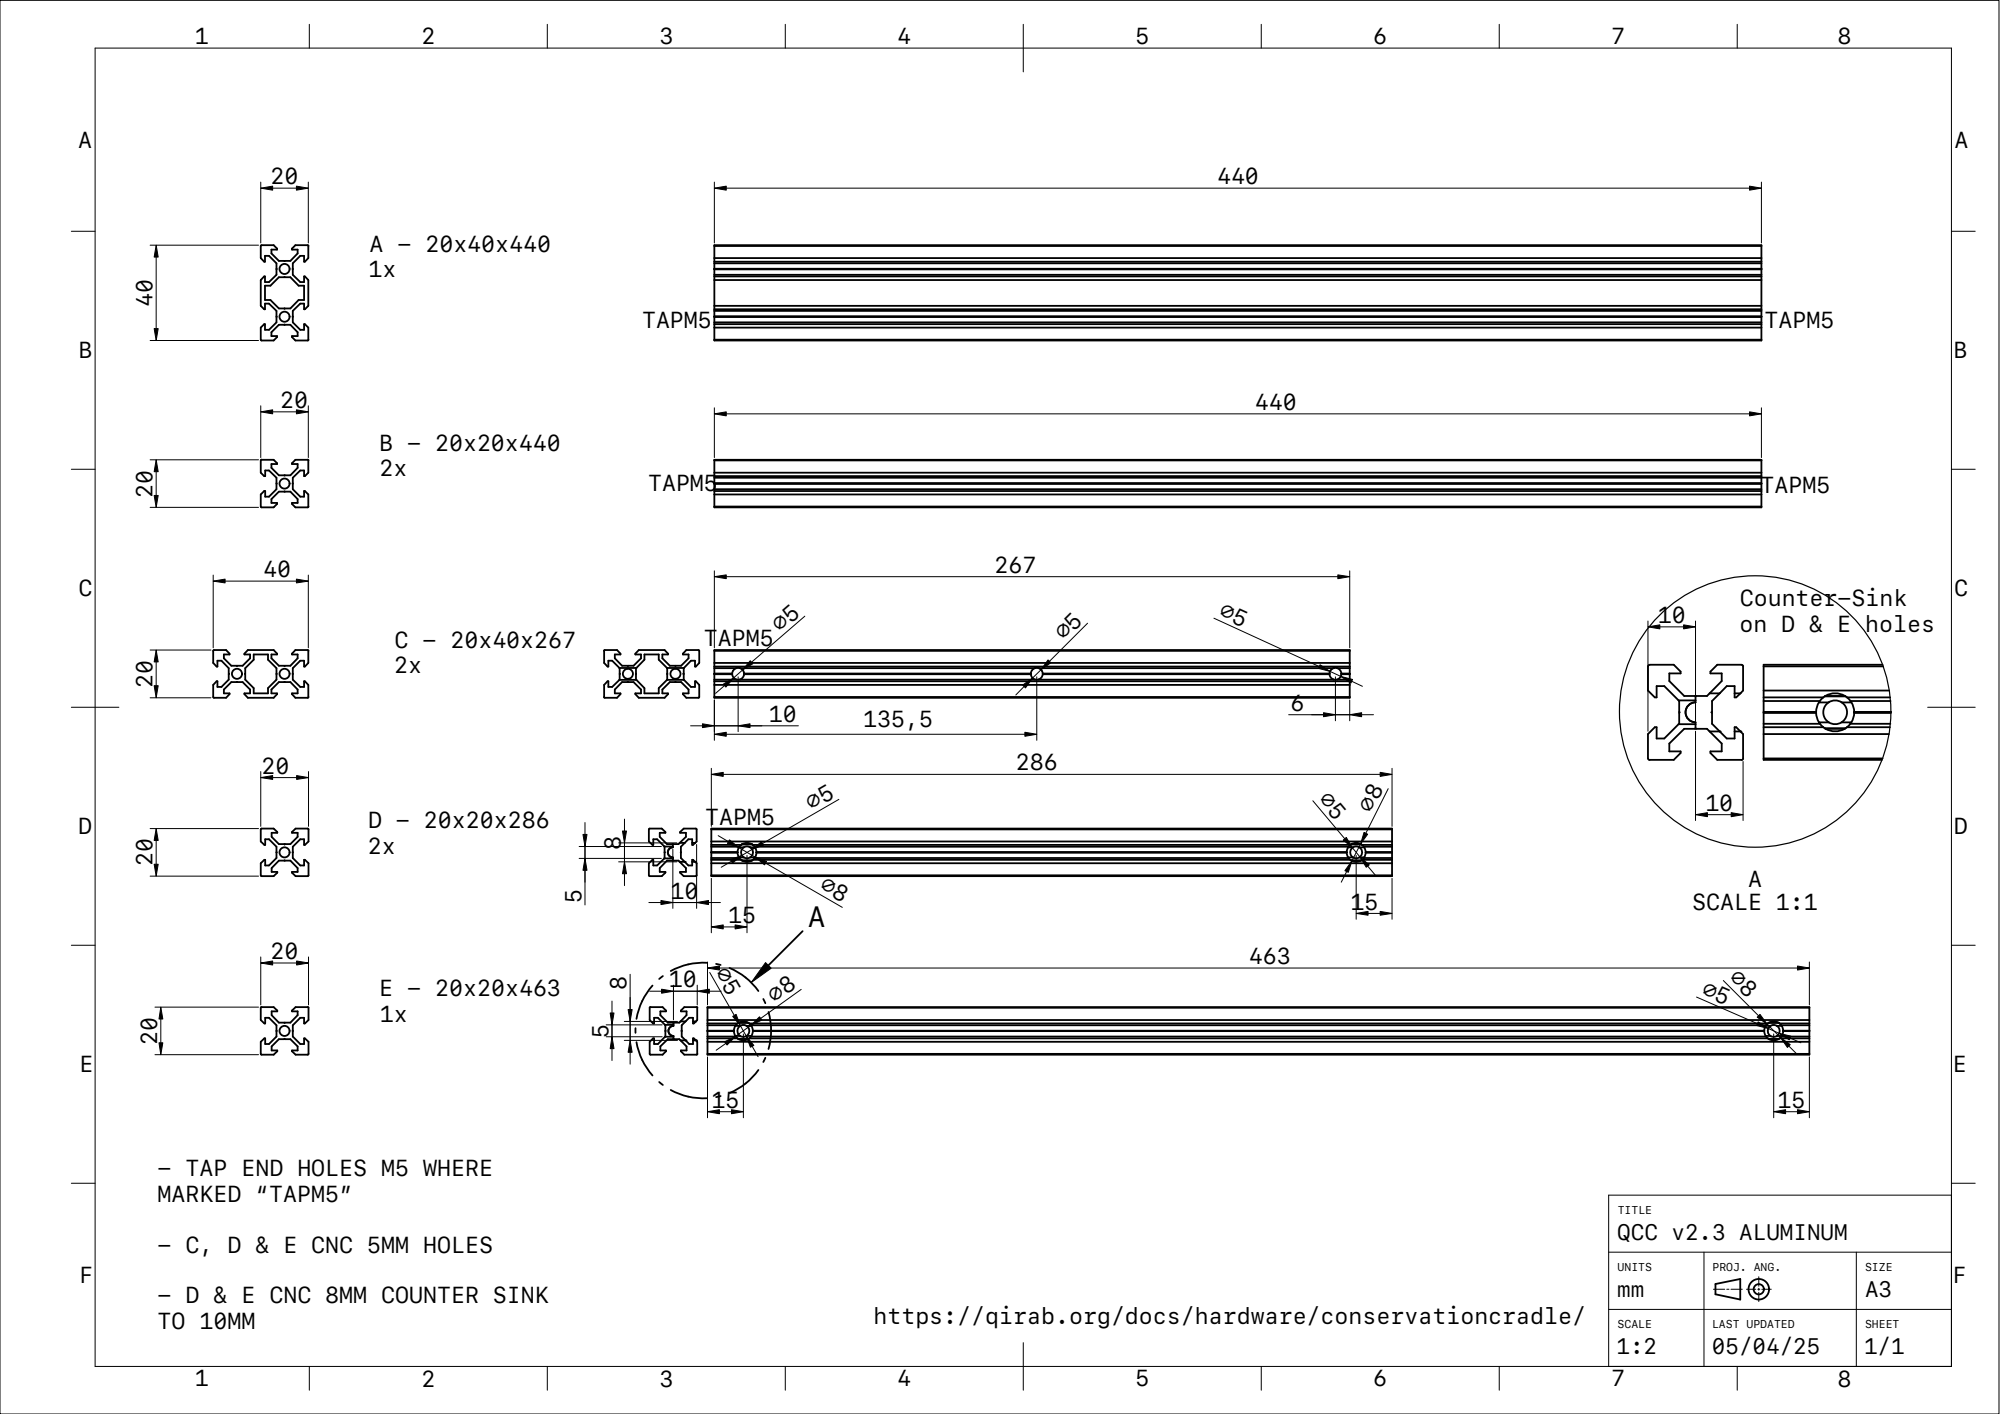
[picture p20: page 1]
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

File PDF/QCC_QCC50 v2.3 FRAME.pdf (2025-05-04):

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

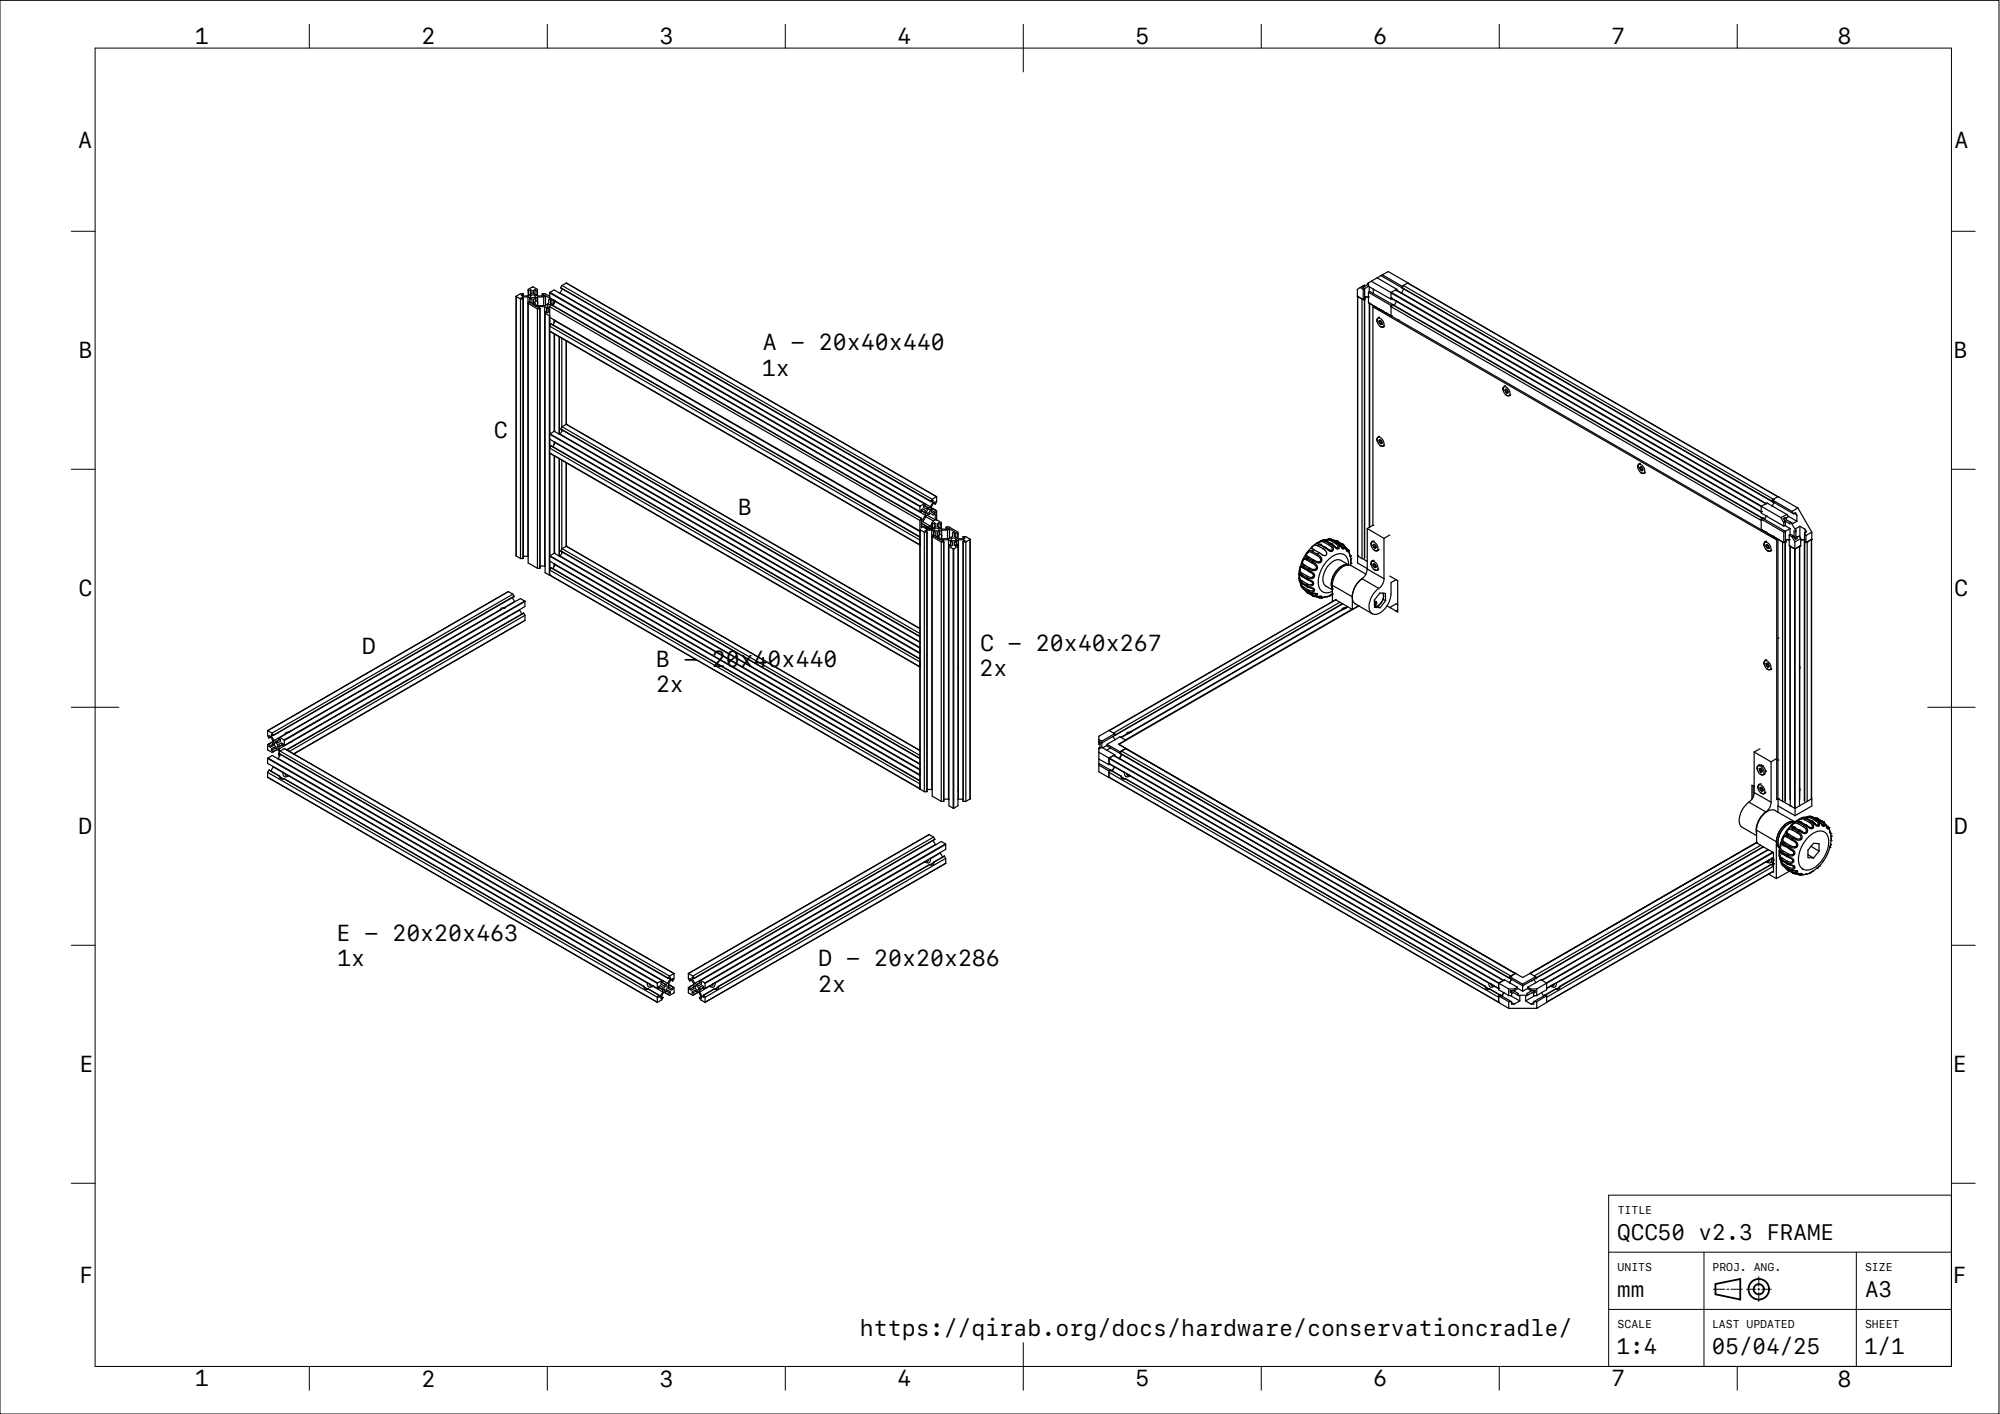
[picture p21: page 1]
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

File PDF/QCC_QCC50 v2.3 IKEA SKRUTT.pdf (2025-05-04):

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

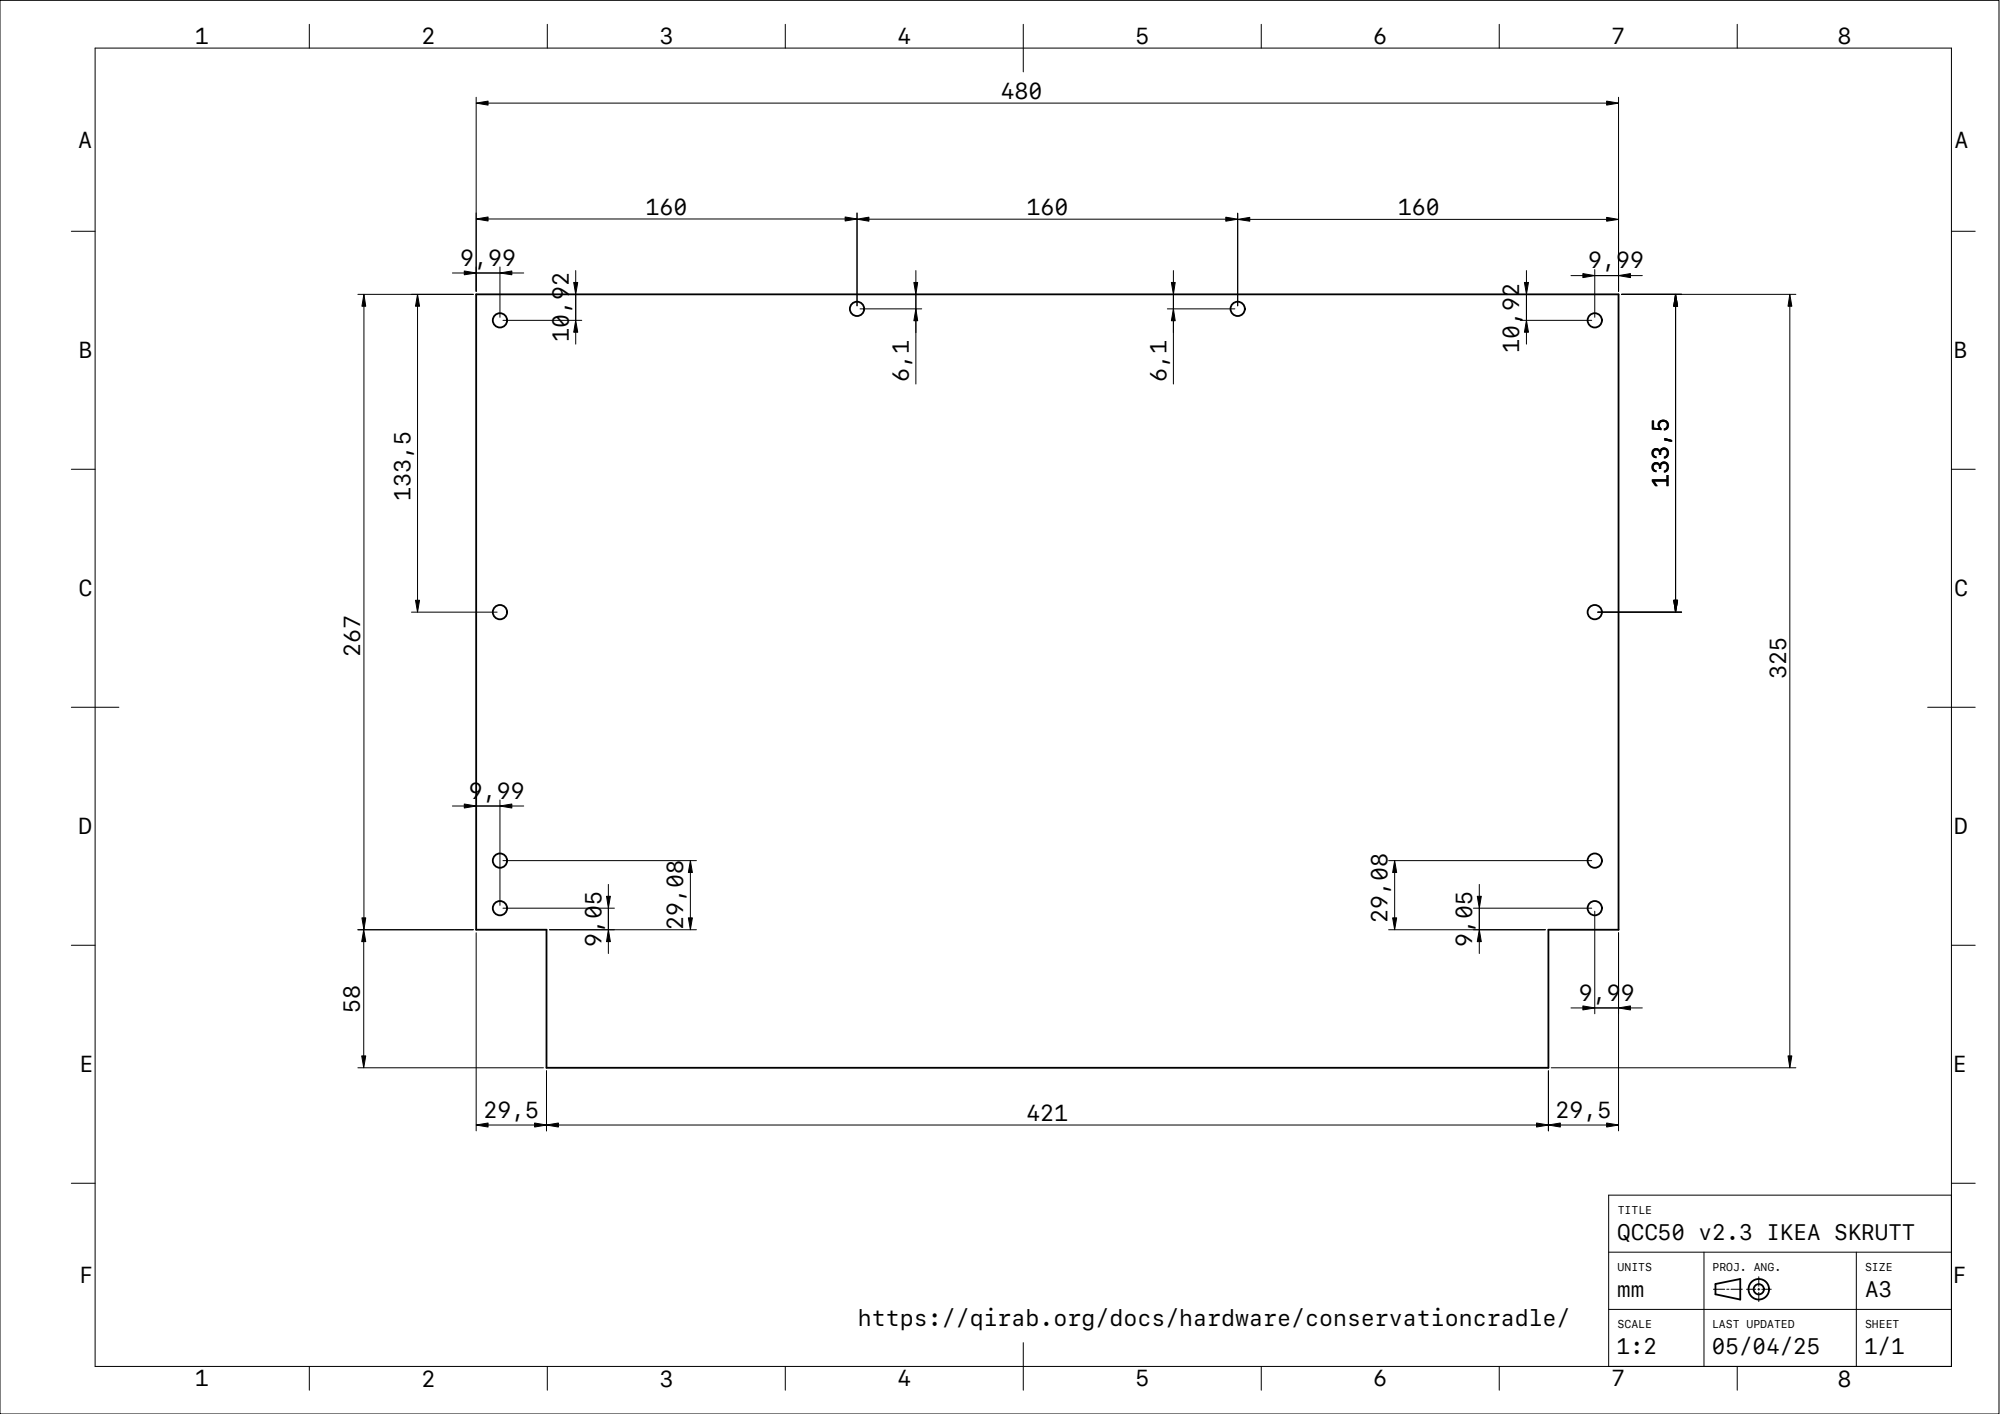
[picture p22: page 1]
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

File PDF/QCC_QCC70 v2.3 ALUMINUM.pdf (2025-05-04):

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

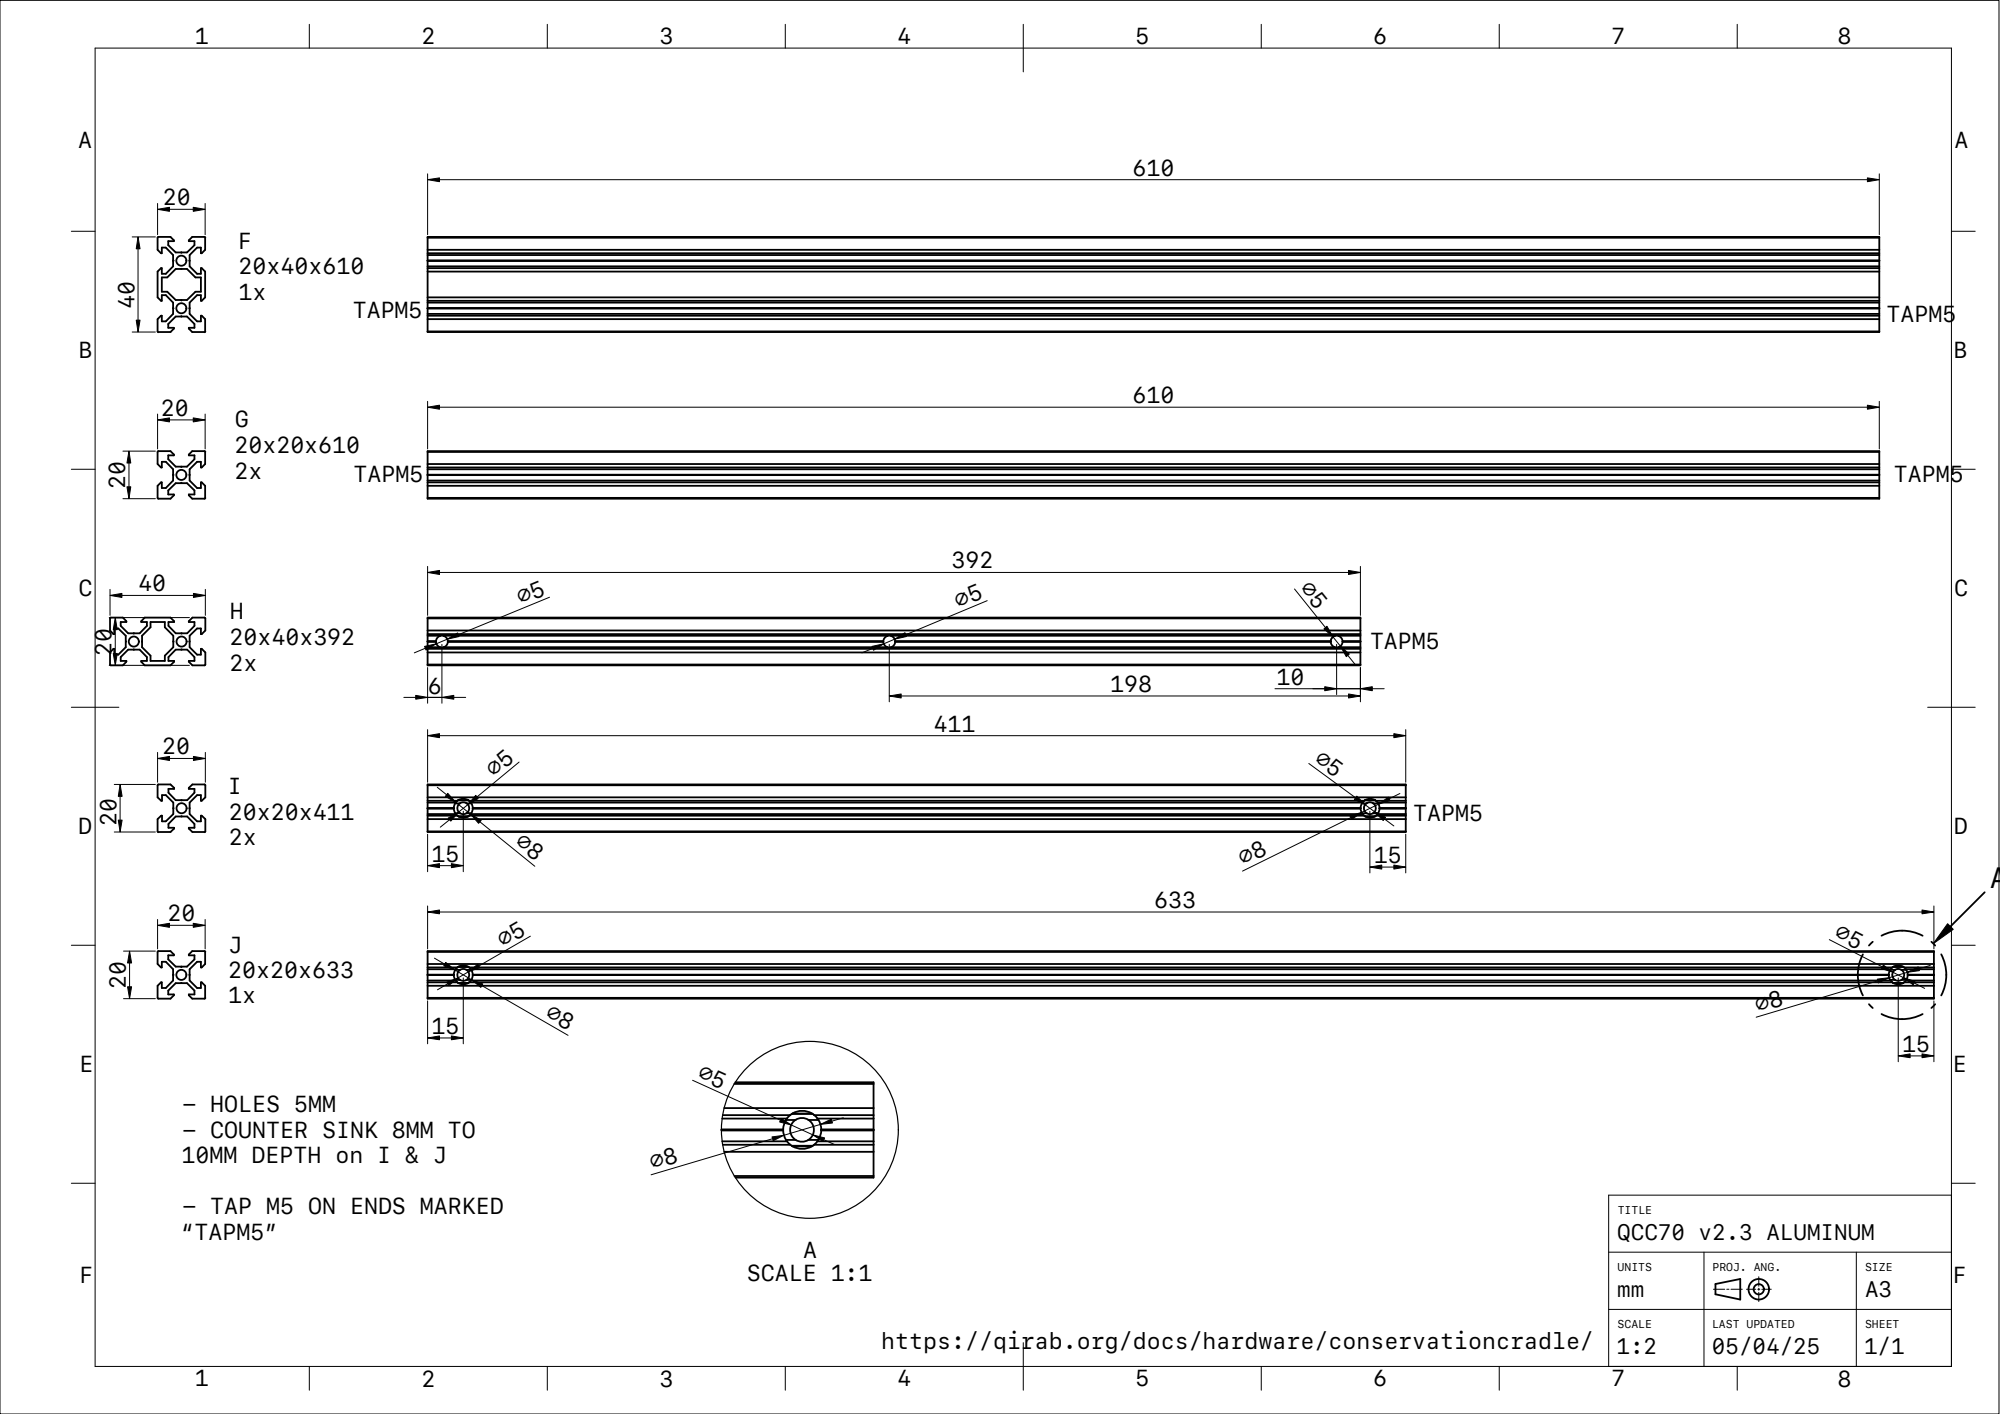
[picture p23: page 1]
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

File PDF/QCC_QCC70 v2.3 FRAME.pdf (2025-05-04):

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

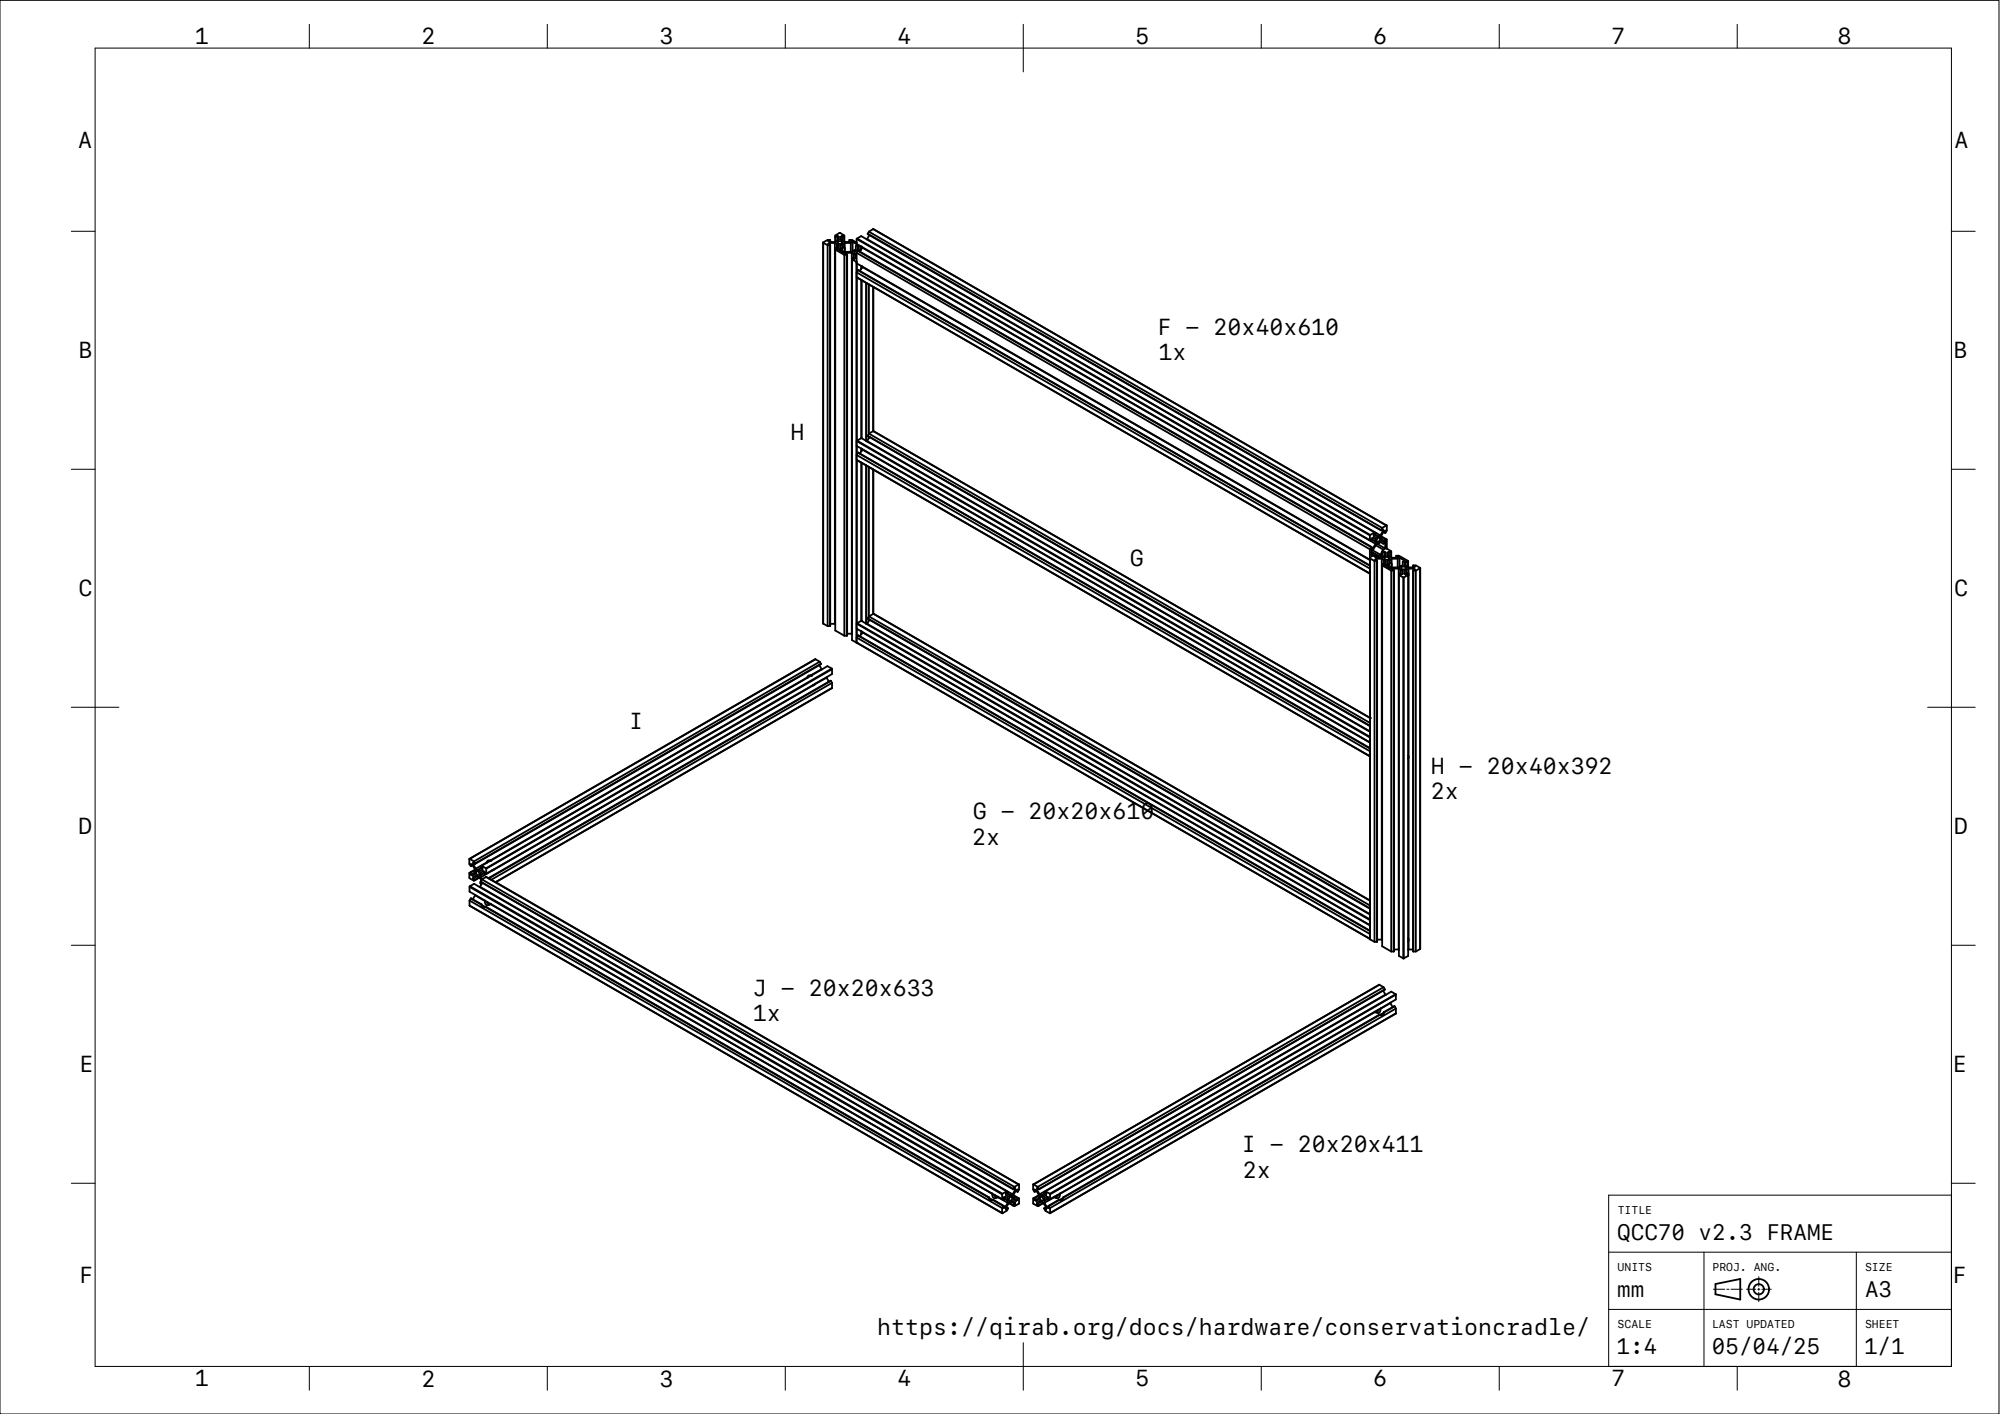
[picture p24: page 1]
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

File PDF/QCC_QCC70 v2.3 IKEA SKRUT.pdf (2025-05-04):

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

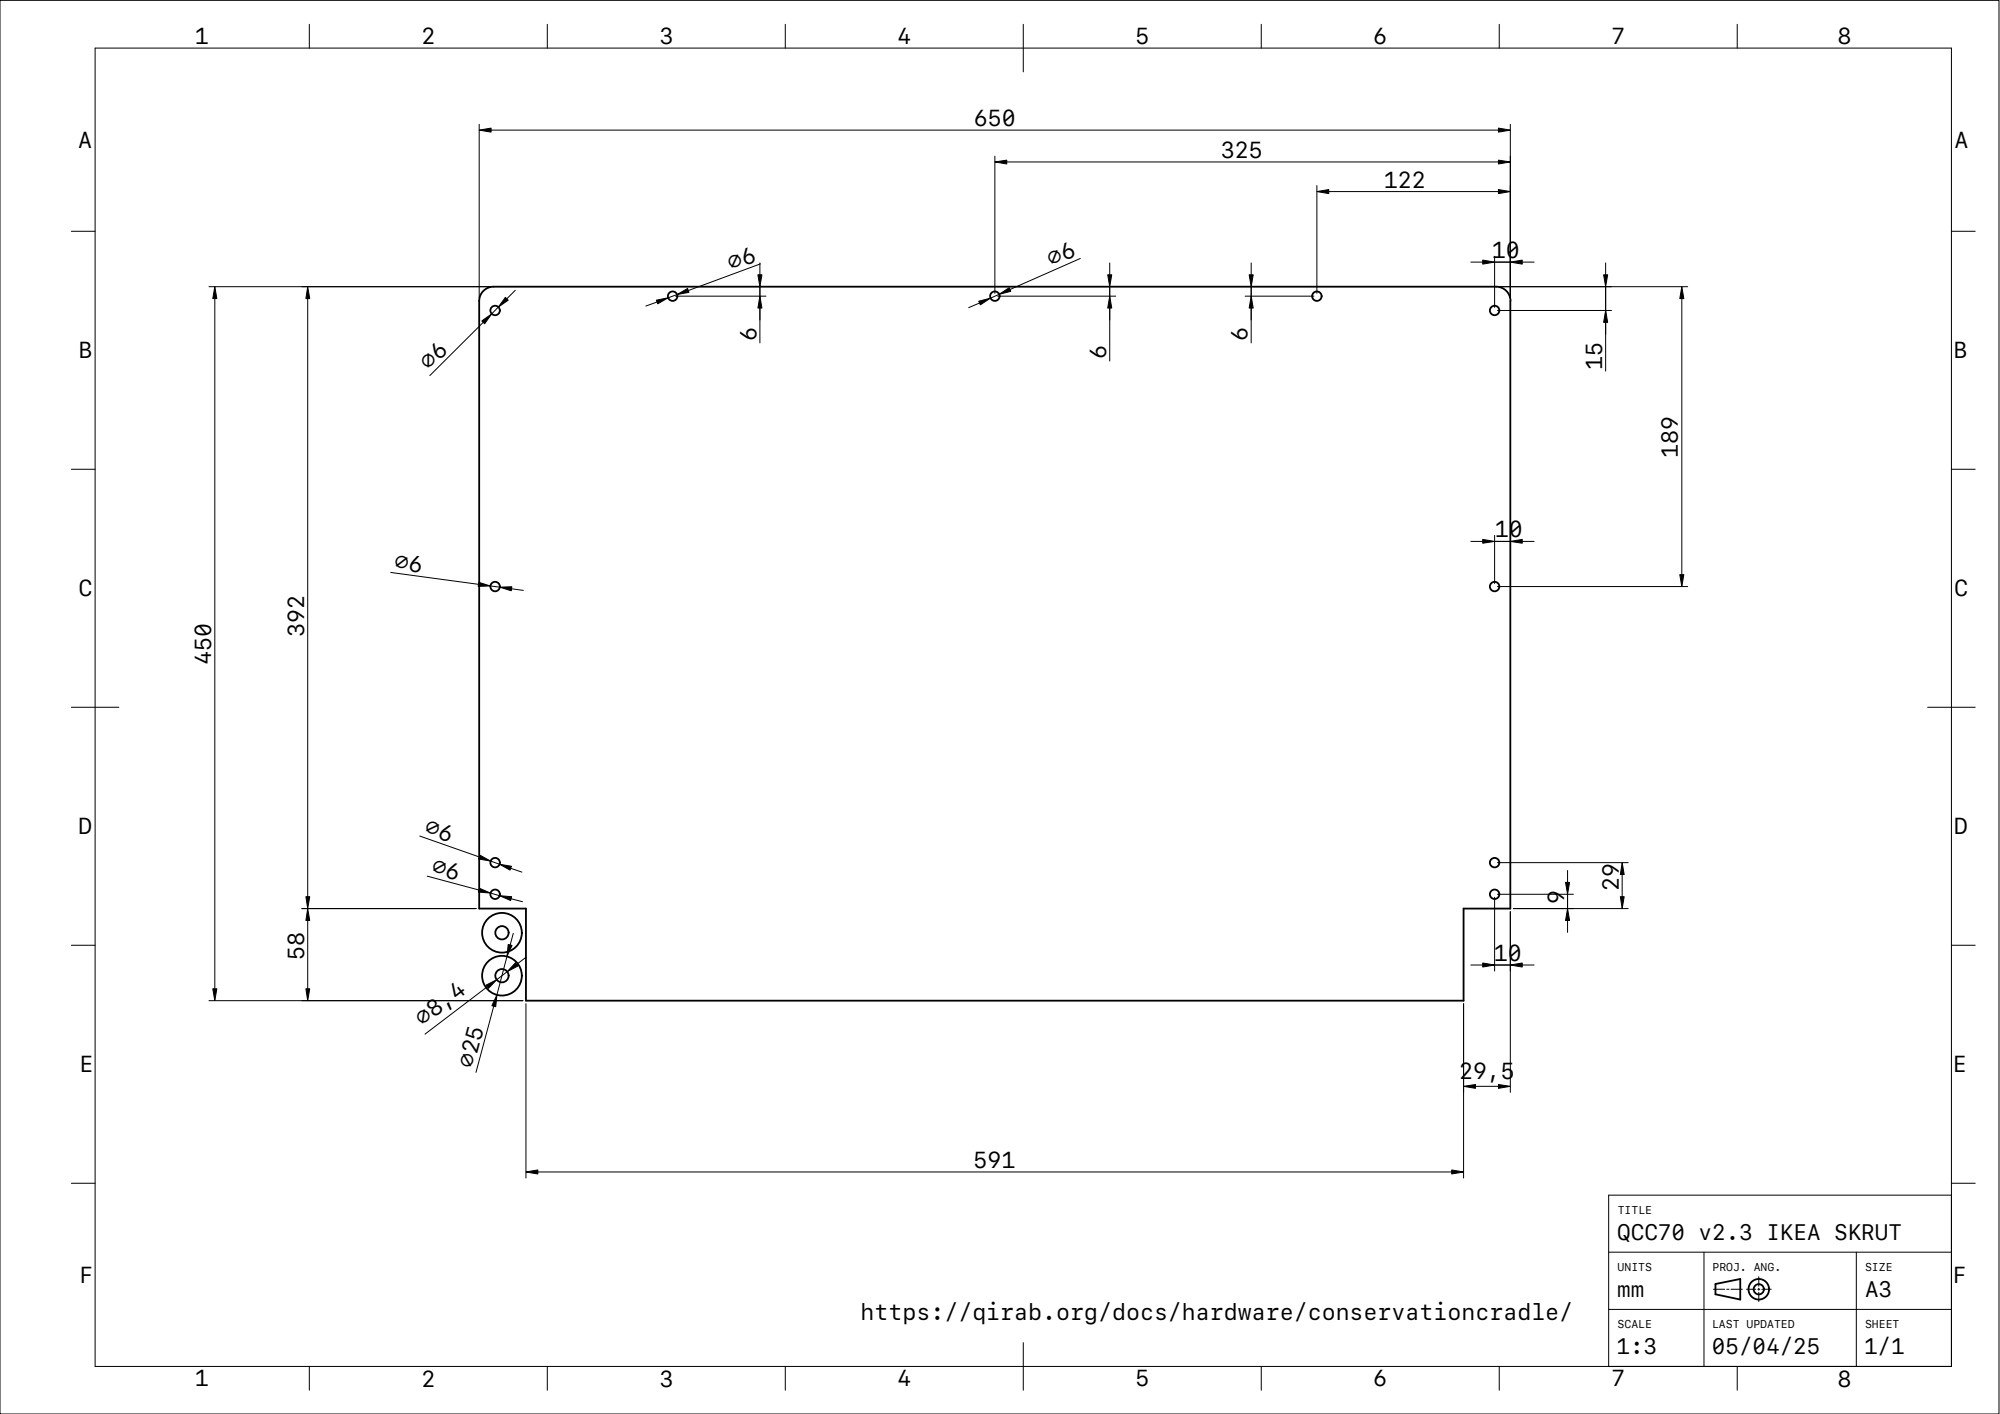
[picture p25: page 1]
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

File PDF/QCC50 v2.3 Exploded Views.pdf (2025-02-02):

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

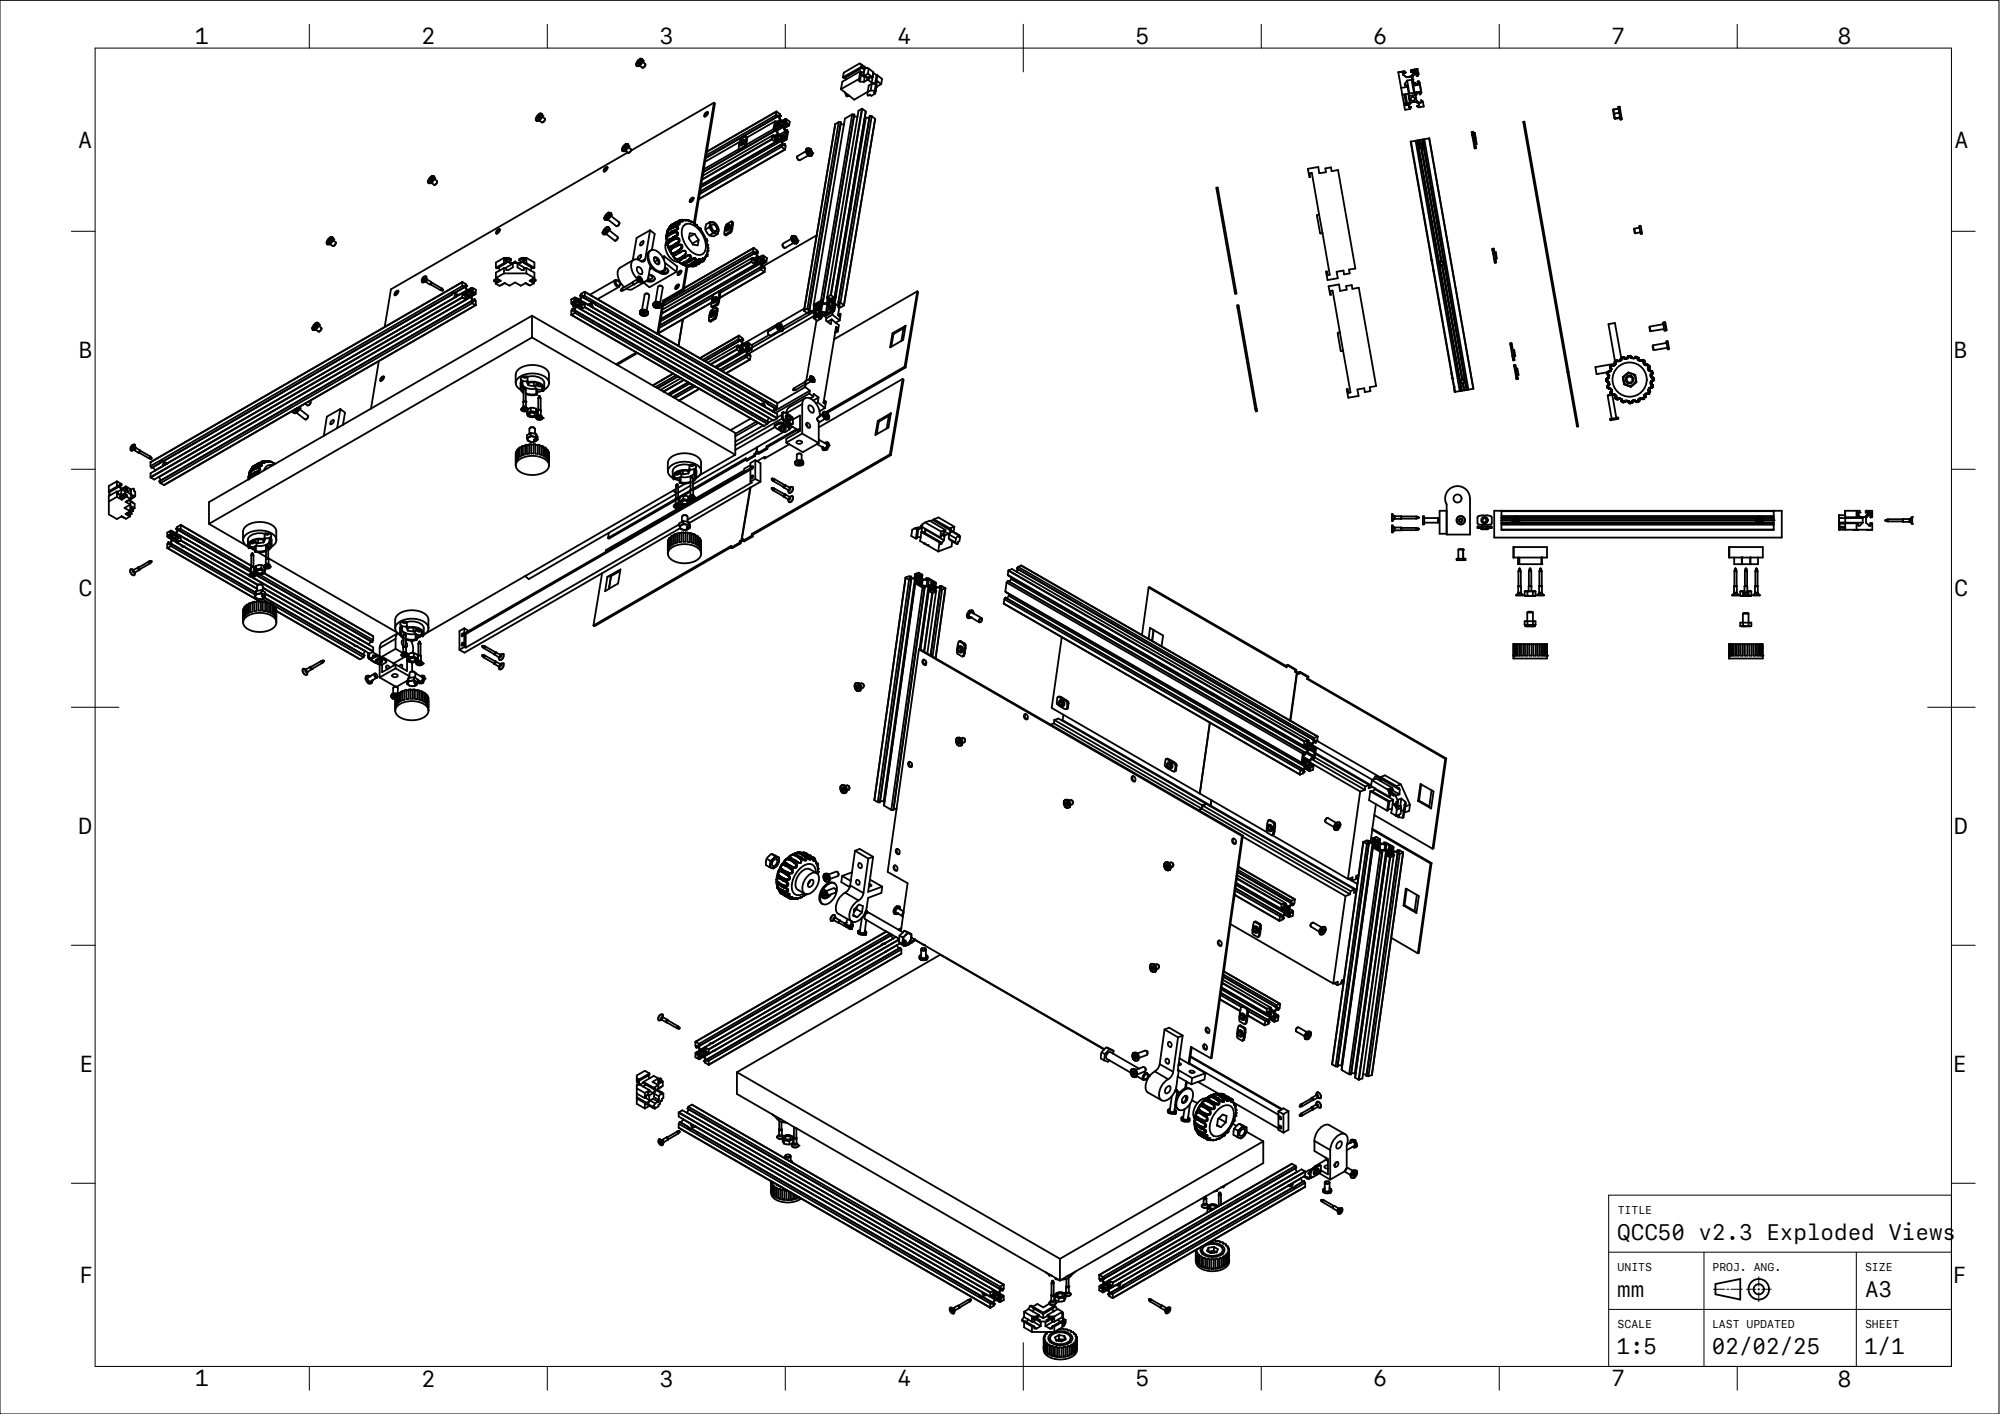
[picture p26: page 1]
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

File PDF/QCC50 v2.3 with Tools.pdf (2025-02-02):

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

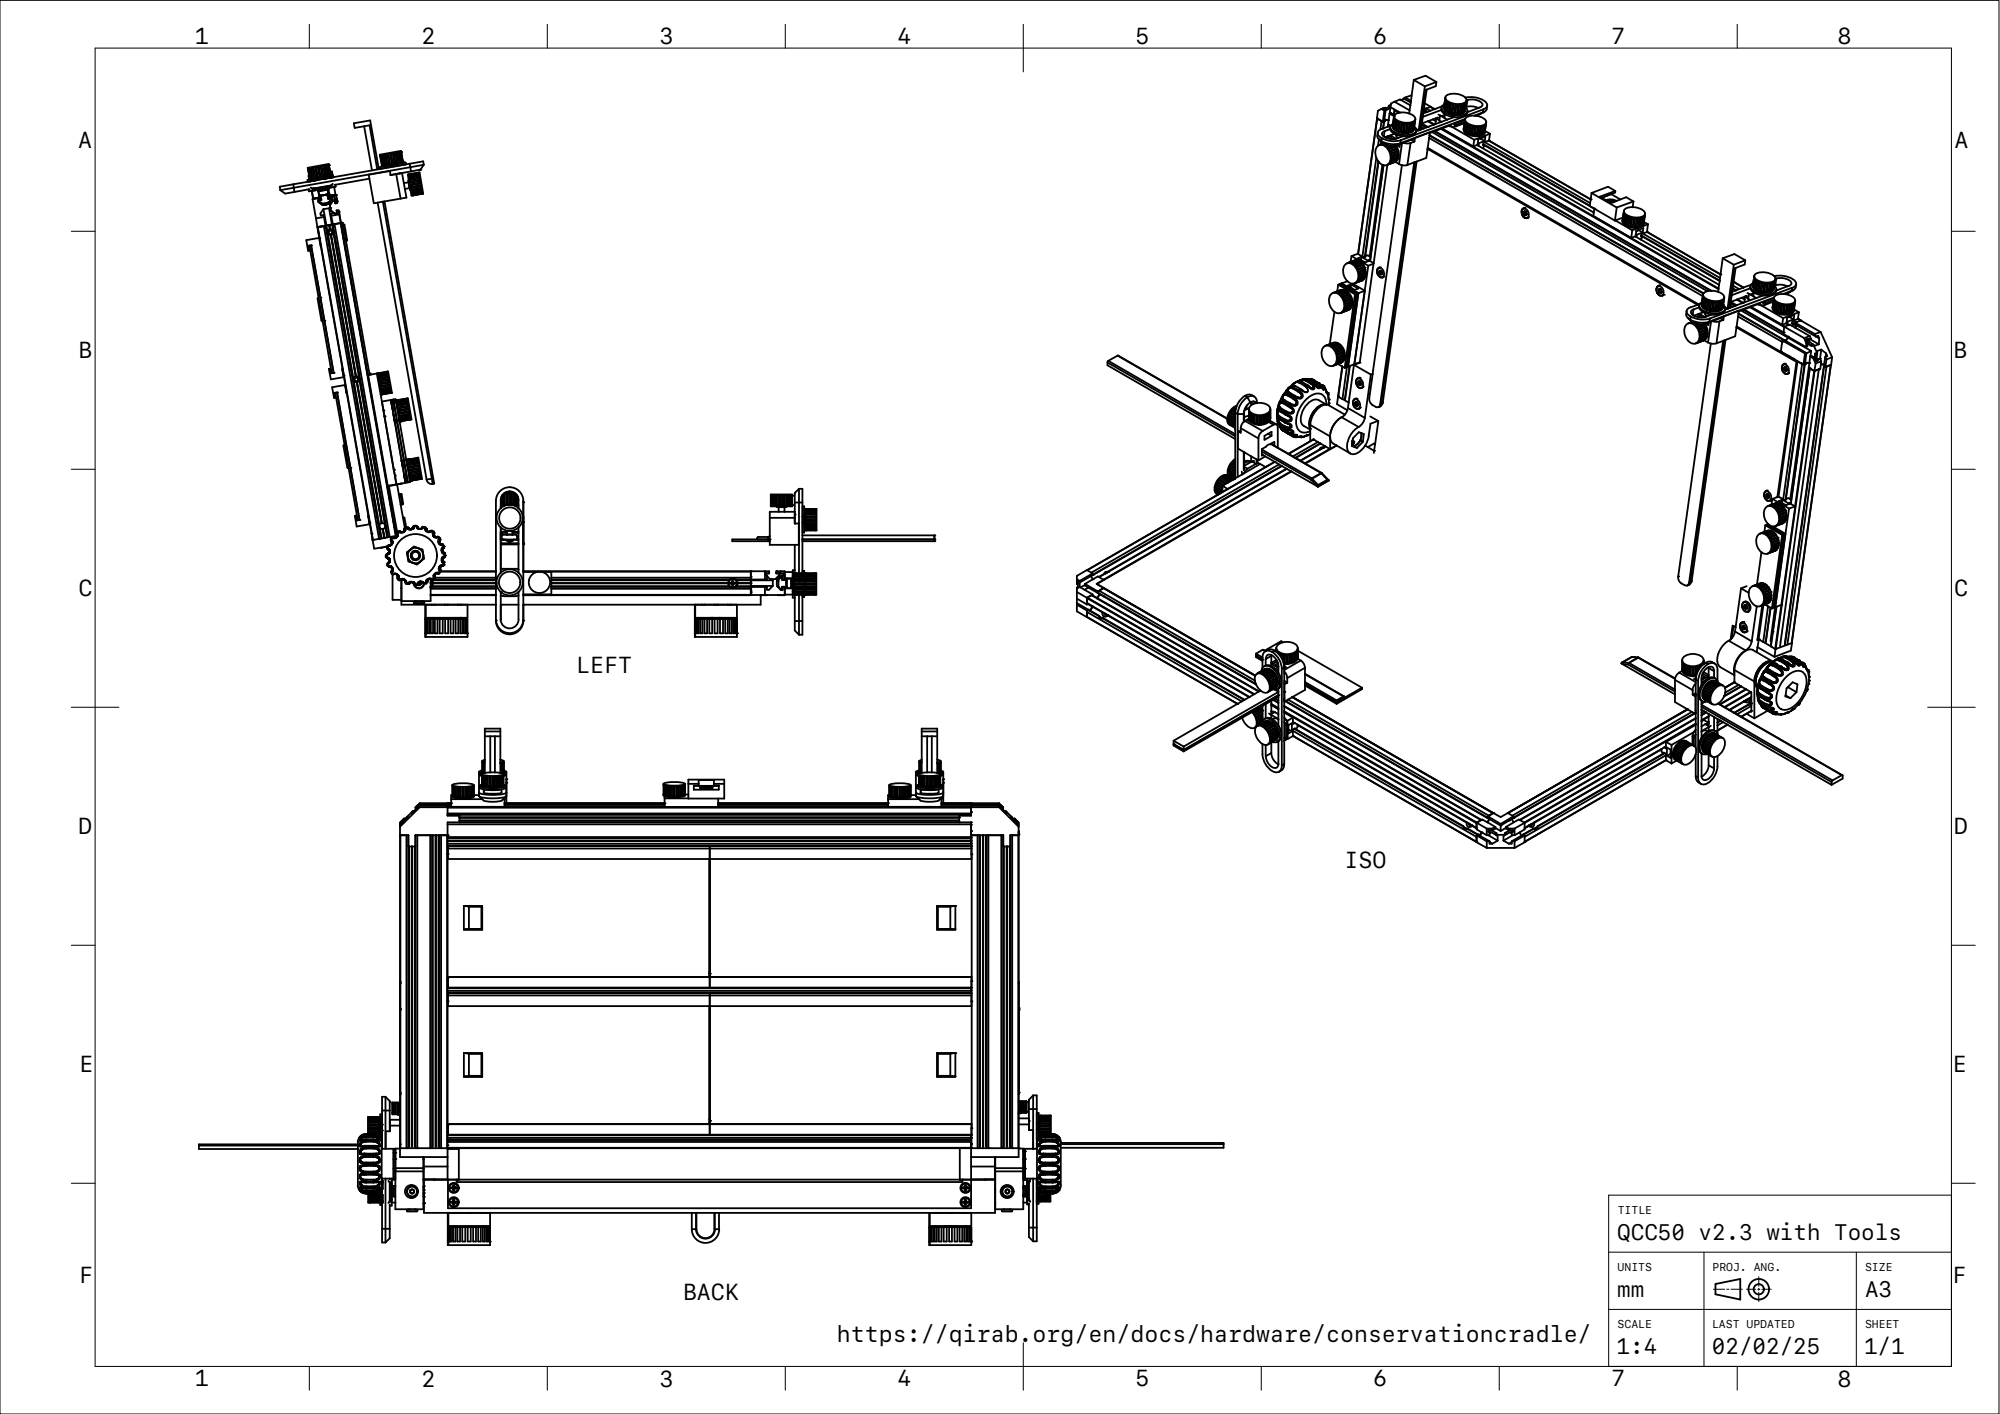
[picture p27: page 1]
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

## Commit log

2023-04-16 stil upload partial
    [QCC50v1_Cap Groove 20.stl, QCC50v1_Cap Groove L.stl, QCC50v1_Cap Groove R.stl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]
2023-04-16 added foot stl
2023-04-16 added knob stl
2023-04-17 added cold shoe stl
    [QCC50v1_ColdShoe.stl]
2023-04-17 added bill of materials
2024-11-07 Beginning to change directory for v2.3 materials
2025-01-16 adding 3D Print, STEP and Image
    [Box Lid QCC44.3mf, Box Lid QCC44.step, Box Lid QCC44.stl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]
2025-01-16 added STEP assembly; moved parts STEP
    [Box Lid QCC44.step, Box Lid QCC50.step, Box Lid QCC70.step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]
2025-01-30 PDFs of QCC50 aluminum and rubber laser cut.
2025-01-31 added PDFs for 50, 70, 44
    [QCC44 V2.3 IKEA SKRUT MAT.dxf, QCC50 v2.3 IKEA SKRUTT.dxf, QCC70 v2.3 IKEA SKRUT.dxf]
2025-02-02 added dirs to PDF dir
    [QCC44 V2.3 IKEA SKRUT MAT.dxf, QCC50 v2.3 IKEA SKRUTT.dxf, QCC70 v2.3 IKEA SKRUT.dxf]
2025-02-02 added new CAD pic with tools
2025-02-02 added PDF with tools and exploded views
    [QCCv2.3_Bill of Materials.xlsx]
2025-03-25 corrected 3MF dir name……………………
    [Box Lid QCC44.3mf, Box Lid QCC50.3mf, Box Lid QCC70.3mf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]
2025-03-25 rmeoved STEP and STL dirs from prints folder.
    All print files will be 3MF. Users can go to the full CAD if they need to make special files.
    [Box Lid QCC44.step, Box Lid QCC44.stl, Box Lid QCC50.step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]
2025-05-04 organized pdf in one folder
    [QCC44 V2.3 IKEA SKRUT MAT.dxf, QCC50 v2.3 IKEA SKRUTT.dxf, QCC70 v2.3 IKEA SKRUT.dxf]
2026-04-27 Removed deprecated channel guide
    [QCC44 Channel Guide.3mf, QCC50 Channel Guide.3mf, QCC70 Channel Guide.3mf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]
2026-05-02 moved USDZ to CAD folder
2026-09-24 prefic 3mf files with QCC
    [QCC Box Lid QCC44.3mf, QCC Box Lid QCC50.3mf, QCC Box Lid QCC70.3mf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]

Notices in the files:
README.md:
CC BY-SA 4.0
